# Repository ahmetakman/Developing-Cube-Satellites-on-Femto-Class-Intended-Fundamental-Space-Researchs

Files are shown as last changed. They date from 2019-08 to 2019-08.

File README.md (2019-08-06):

# Developing-Cube-Satellites-on-Femto-Class-Intended-Fundamental-Space-Researchs

The project won the second place in the coding category in the TUBITAK Inter-High School Research Projects Competition.
Project designed in Autodesk Eagle Pcb design program
#pasword for zip : licenced_design

Projenin Türkçe ismi "Temel Uzay Araştırmalarına Yönelik Femto Sınıfında Küp Uydu Geliştirilmesi"
Proje Tübitak Liseslerarası Araştırma Projeleri Yarışmasında kodlama dalında bölge ikinciliği aldı.
Proje Autodesk Eagle Pcb tasarım programında tasarlandı.
#zip dosyasının şifresi : licenced_design

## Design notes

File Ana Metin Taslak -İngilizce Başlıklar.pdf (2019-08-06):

THE REPORT OF THE PROJECT WHICH IS DEVELOPING CUBE SATELLITE ON FEMTO CLASS INTENDED FUNDAMENTAL SPACE RESEARCHS

TABLE OF CONTENTS

### 1.0 Introduction

Yapay uydular, Sputnik ile başlayan uzay çağının en önemli elemanları olmuşlardır.
Günümüzde | bu | uydular, | gerçekleştirdikleri | kritik | görevlerle | insanlığa | hizmet
etmektedirler. İletişim, uzaktan algılama, veri toplama, navigasyon, keşif ve bilimsel
deneyler | kullanıldıkları | alanlardan | sadece | bir | kısmını | oluşturmaktadır. | Uzay
teknolojisine yapılan yatırımlar hiç bir zaman boşa gitmemiş, mühendislikte ve bilimdeki ilerlemeleri tetikleyen bir unsur olmuştur. Ayrıca bu gelişmeler de uzay teknolojisinin ileriye gitmesinde ve gelişmesinde büyük rol oynamıştır. Günümüzün uzay araçları ile onların atalarını karşılaştırdığımızda, bugünün uydularının çok daha küçük, hafif ve kompakt yapılar olduklarını görürüz. Uzayla ilgili bir projenin risk ve maliyet gereksinimlerini dikkate alırsak, bu durum çok önem arz etmektedir. Yüzlerce, hatta binlerce kilogramlık uydular, aynı zamanda görev bütçeleri için de ağır bir yük teşkil etmektedirler. Bu nedenle, küçük uydular tasarımları, testleri, onaylaması ve fırlatma maliyetlerindeki avantajlardan dolayı dikkat çekmektedirler. (Sarı, 2010) (Aslan, 2015).

Son yıllarda küp uyduların artan yetenekleri ile uzay sektöründe büyük atılımlar meydana gelmiştir. Üretilen ve uzayda çalışan ilk küp uydularla uzay kalifiye ürünler de kullanmadan uzay sistemlerinin geliştirilebileceği ve farklı görevlerde kullanılabileceği gösterilmiştir. Bir öğrenci eğitim projesi olarak başlayan küp uydu tasarım projeleri şimdi farklı amaçlarla gelişerek yüksek öncelikli bir konu haline gelmiştir. Birçok kişi ve kurum, bu konu hakkında çalışmaları teşvik etmektedir. (Akay, 2012)

Küp uydular ile temel uzay çalışmaları yapılabildiği gibi, gözetleme uyduları gibi ileri seviye çalışmalar da çoklu küp uydular kullanılarak belli ölçülerde yapılabilmektedir. (Baş, 2017)

### 1.1 Goal of The Project

Ülkemizde yeni gelişmeye başlayan uzay sektöründe yapılan çalışmaların azlığı sebebiyle küçük çapta uyduların erişimi ve geliştirilmesi göreceli olarak daha kolaydır. Ülkemizde ve dünyada mevcut geliştirilmiş olan Femto (0-100 gr ağırlıklarında) pek az uydu bulunmaktadır. Bu uydular görev olarak temel telemetri verileri gönderebilen altsistemlerden oluşur. Proje kapsamında geliştirdiğimiz uydu platformu ile var olan bu açığı gidererek temel uydu fonksiyonlarını yerine getirebilen ek görev yükü olarak kamera modülünü de bulunduran gömülü sistem çözümü niteliğinde bir platform geliştirmek bu projenin amacını oluşturmaktadır.

### 1.2 Electronic Design and Development

### 1.2.1 Component Selection: Projemizde ana işlem birimi olarak uzay ürünleri konusunda

geçmiş tecrübesi bulunan Texas Instruments firması tarafından geliştirilen SimpleLink CC1310 RF MCU (cc1310, 2016) tercih edilmiştir. Ultra Low Power sınıfı bir mcu (mikrodenetleyici) olan CC1310 çok düşük güç tüketimi sağlamaktadır. Ayrıca üzerinde gömülü durumda RF (radyo iletişim) çekirdeği de bulunmaktadır. Böylelikle sistem üzerinde iki ayrı ana birimi birleştirerek yerden tasarruf etmeyi sağladık. Sensör kartı üzerinde bulunmakta olan Mpu 9250 (Invensense, 2016) sensör entegresi jiroskop manyetometre ve ivmeölçer sensörlerini barındırmaktadır sensör kartı üzerindeki BME280 (Bosch, 2015) entegresi ısı sıcaklık basınç nem ölçümleri yapabilmektedir.

Uydu platformu üzerinde kamera arayüz kartı ve kamera bulundurmaktadır. Kamera olarak dcmi arayüzüne sahip (OV5640,2011) opsiyonel görüntü sensörüne yer verdik. Kamera arayüz kartında ise ST Microelectronics firması tarafından üretilen stm32l4 (St MicroElectronics

,2017) serisi Ultra Low Power sınıfı dcmi arayüzüne sahip çok düşük güç tüketimli bir mcu kullandık.

Sistem üzerindeki hafıza kartı (sd card) modülü ile toplanan verilerin kaydedilmesini sağlayarak kapsama alanı dışında elde edilen verilerin kaybolmamasını sağladık.

Enerji ve enerji yönetiminde düşük enerji tüketimine sahip Texas Instruments tarafından üretilen BQ25504 (Texas Instruments, 2015) enerji yönetim entegresi kullanılmıştır.

Komponent seçimlerinde uzay kabul edilebilirlik standartları göz önünde bulundurulmuştur. Komponentlerin görev açıklaması ve teknik ayrıntılar raporun ilgili tasarım bölümünde mevcuttur.

1.2.2 Eagle: İlk olarak cadsoft firması tarafından geliştirilen daha sonra da Autodesk firması tarafından satın alınan elektronik tasarım aracı olan Eagle programının projede 8.5.1 sürümü kullanılmıştır. Gelişmiş şematik ve pcb tasarım arayüzü geniş kütüphane desteği sebebiyle Eagle programı tercih edilmiştir. (Autodesk, 2017)

### 1.3 Embedded System Programming

### 1.3.1 Sensor Controller Studio and Code Composer Studio: Texas Instruments Tarafından

geliştirilen ve kendi gömülü sistem ürünlerini programlamak için geliştirilmiş programlar ve dillerdir. Sensor Controller Studio (Texas Instruments,2017) uyduda kullandığımız cc1310 işlemcisinin içinde bulunan Sensor Controller Engine çekirdeğini c dilinde programlamaya pin konfigürasyonunu yapmaya imkân veren güçlü bir araçtır. Code Composer Studio (Texas Instruments,2017) ile de işlemcimizin ana çekirdeğini programlamak için kullandığımız C dilinde (Deitel, 2010) programlama seçeneği sunan güçlü bir araçtır.

### 1.3.2 Keil: Kamera arayüzü bloğunda kullandığımız stm32l4 işlemcisini programlamak için

kullanılan üreticinin de desteklediği C dilinde bir gömülü yazılım aracıdır. (Keil, 2017)

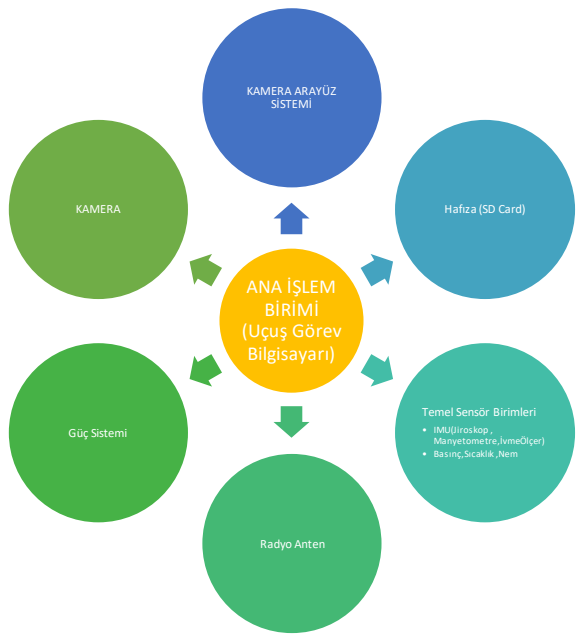
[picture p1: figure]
ANA İŞLEM BİRİMİ (Uçuş Görev Bilgisayarı); KAMERA ARAYÜZ SİSTEMİ; Hafıza (SD Card); Temel Sensör Birimleri; • IMU(Jiroskop , Manyetometre,İvmeÖlçer) • Basınç,Sıcaklık ,Nem; Radyo Anten; Güç Sistemi; KAMERA

Şekil 1.0 Femto Satellite General Relation Diagram

### 2.0 Method

Projede yer alan iki ana sistem olan, kamera sistemi ve ana sistem; iki ana parça olarak, elektronik tasarım ve programlama gerçekleştirilmiştir.

2.1 Proje Yapım Basamakları

2.1.1 Ana Görev Uçuş Bilgisayarı Kartı Tasarımı

2.1.2 Sensör ve RF Anten Kartı Tasarımı

2.1.3 Güç ve Güç Yönetim Sistemi Kartı Tasarımı

2.1.4 Kamera Arayüz Kartı Tasarımı

2.1.5 Kamera Kartı Tasarımı

2.1.6 Ana İşlemci Programlanması

2.1.6.1 Sensör Kontrolcü Çekirdeği Programlanması

2.1.6.2 Ana çekirdek Programlanması

2.1.7 Kamera Arayüzü Sistemi Programlanması

### 3.0 Finding and Applying

### 3.1 Main Mission Flight Computer Board Design

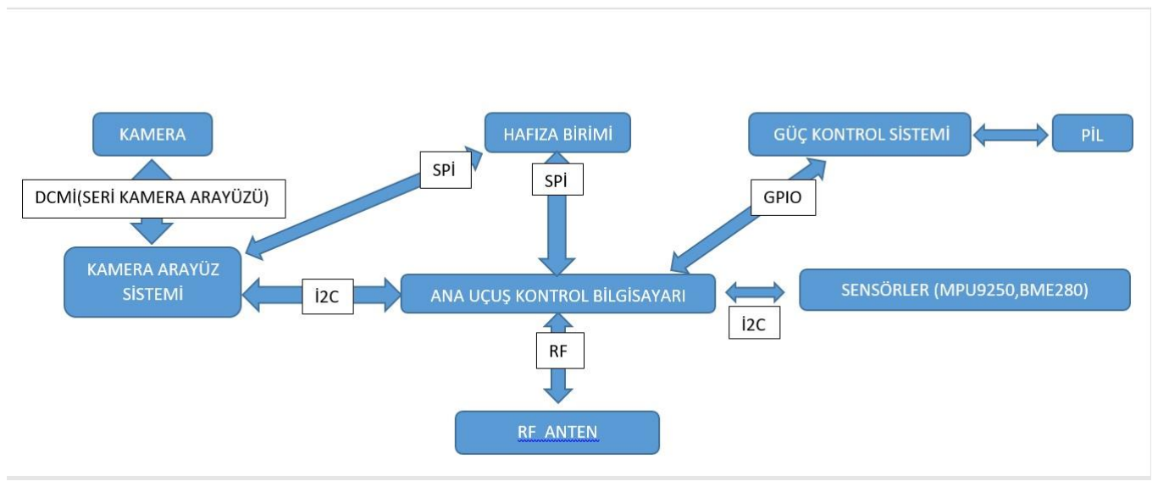
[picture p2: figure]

Şekil 1.1 Subsystems General Interface Diagram

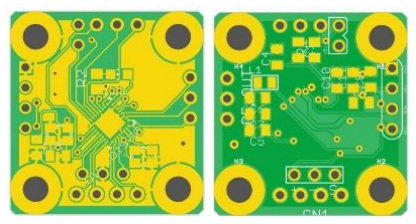
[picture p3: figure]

Şekil 1.2 Board Design Picture

Ana Görev Uçuş Bilgisayarı Kartı diğer altsistem birimlerinin tümünü yöneten kart konumundadır. Bu nedenle üzerinde bulunan ana işlem birimi cc1310 rfmcu entegresinin giriş ve çıkışları Şekil 1.1 de belirtilmiş olan arayüz diyagramımıza göre tasarlanmıştır. Diğer altsistemler ile gerçekleşecek olan iletişimi sağlamak üzere en uygun yerlere ilgili pinler yerleştirilmiştir. Kart üzerindeki oluşacak ısı, toprak (GND) hattının alt ve üst katmanda genişletilmesi ile dağıtılmıştır. Kart boyutları mekanik tasarım ile küp şeklinin tamamlanması için az bir farkla dikdörtgen konumlandırılmıştır.

### 3.2 Sensor and RF Antenna Board Design

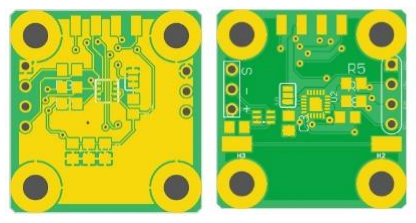
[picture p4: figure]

Şekil 1.3 Board Design Picture

Sensör ve RF Anten Kartı sistemde bulunan temel sensör birimlerini ve RF (radyo iletişimi) filtresi ile antenini üzerinde bulundur. Ana Görev bilgisayarı ile şekil 1.1 de belirtilmiş olan iletişimi sağlamak üzere ilgili pinler dahili jiroskop manyetometre ivmeölçer bulunduran MPU9250 IMU sensör entegresi ve dahili atmosferik sensör bulunan BME280 sensör entegresinden sağlanan arayüz çıkışları Ana Görev Uçuş Bilgisayarı Kartı ile üst üste tam oturacak şekilde bırakılmıştır. Bu kartın tasarımında da ısı dağılımı ve mekanik boyutlar gibi konularda Ana Görev Uçuş Bilgisayarı Kartı ile aynı anlayış benimsenmiştir.

### 3.3 Power and Power Management System Board Design

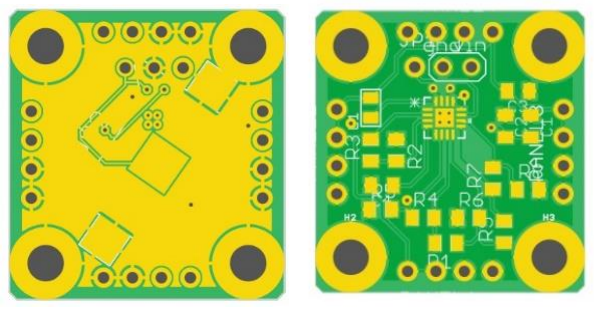
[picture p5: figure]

Şekil 1.4 Board Design Picture

Uydumuzun çevresini kaplayarak enerji ihtiyacını sağlayan güneş panel hücrelerinden gelen enerjiyi kontrol ederek pili şarj eden ve sisteme verilen enerjiyi kontrol eden Texas Instruments firması tarafından üretilen BQ25504 enerji yönetim entegresini üzerine konumlandırmış olduğumuz güç ve güç yönetim kartımız yine diğer alt sistemlerle aynı boyutlarda ve uyum içerisinde tasarlanmıştır. Kartımızın alt katmanında yalnızca pil yuvası bulunmaktadır diğer tüm komponentler üst katmandadır. Ayrıca enerji yönetim entegresi ana kontrol birimine pil hakkında bilgi de vermektedir.

### 3.4. Camera Interface Board Design

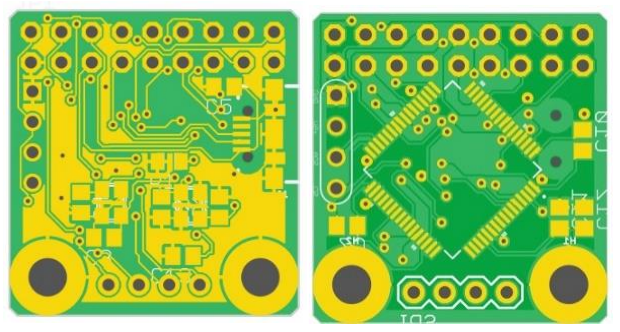
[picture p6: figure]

Şekil 1.5 Board Design Picture

Uydumuzu diğer benzerlerinden ayıran en önemli özellik olan kamera bulundurma yetisini kamera verilerini işleyerek fotoğraf haline getirebilen kamera arayüz kartımız kazandırmaktadır. Kartımız üzerinde ARM tabanlı bir mikro işlemci olan STM32L4 mevcut. Kartımız şekil 1.1 da yer aldığı gibi DCMI (seri kamera arayüzü) portu ile kendi geliştirmiş olduğumuz kamera modülü ve aynı pin çıkışlarına sahip diğer kamera modülleri ile de kullanılmasına imkân veren bir yapıda. Kartımız diğer altsistem kartları ile aynı felsefe ve tam uyum içerisinde tasarlanmıştır.

### 3.5. Camera Board Design

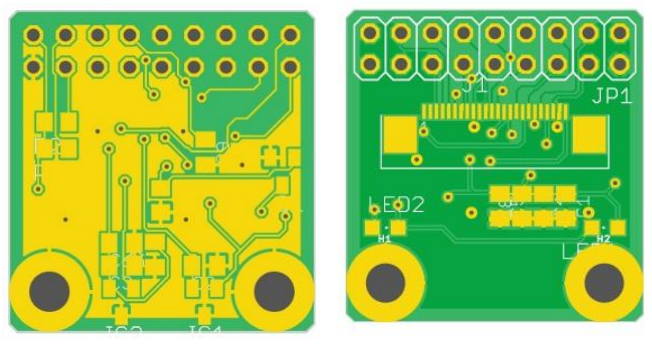
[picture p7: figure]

Şekil 1.6 Board Design Picture

Kamera kartımız omnivision firması tarafından geliştirilmiş olan OV5640 görüntü sensörüne tam uyum sağlayarak şekil 1.1 da gösterilen DCMI portu ile çıkış verilmiştir. Kartımız diğer altsistemlerle tam uyum sağlayan bir yapıdadır (şekil 1.6).

### 3.6. Main Microcontroller Programming

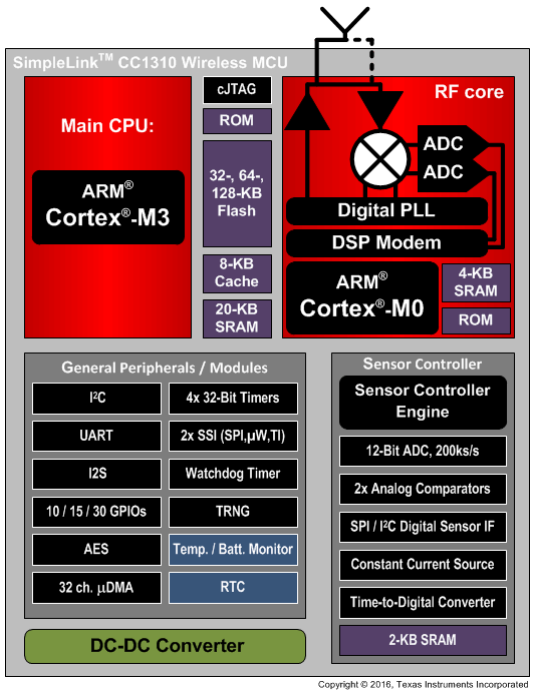
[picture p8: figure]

Şekil 1.7 Main Microcontroller Functional Diagram

Projemizde temel uydu fonksiyonlarını yerine getirirken aynı zamanda enerji tüketimini en alt düzeyde tutmak mecburiyetiyiz. Bundan ötürü sistemimizde kullanmış olduğumuz Ana işlem birimi olan CC1310 RF mcu’su da düşük güç tüketimi odaklı tasarıma sahip . Şekil 1.7 de görebileceğiniz üzere ikisi programlamaya ihtiyaç duyulan biri 3 ayrı çekirdekten oluşmaktadır. Ana çekirdek code composer studio ortamında sensör kontrolcüsü ise sensor controller studio ortamında C dili ile kodlanarak programlanmıştır.

### 3.6.1. Sensor Controller Core Programming

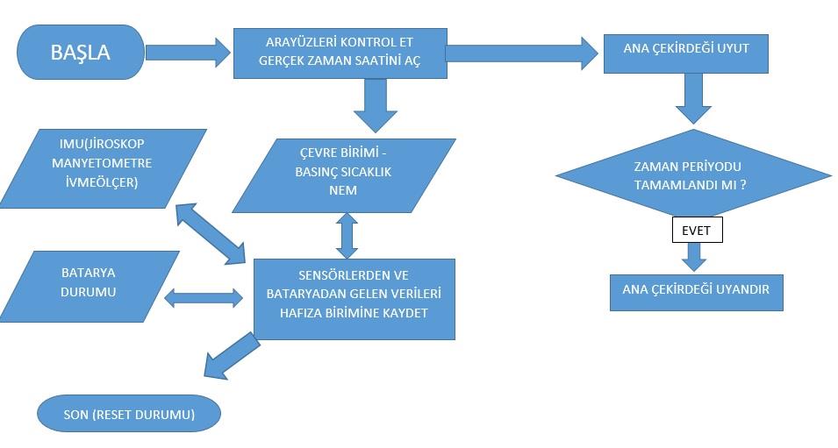
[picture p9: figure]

Şekil 1.8 Sensor Controller Core Algorithm

CC1310 RF mcu’nun içerisinde enerji tüketimini en aza indirmek üzere ana işlemciye bağımlı slave (emir alan) durumunda bir sensör kontrolcü çekirdeği mevcuttur. Bu çekirdeği programlamak üzere Texas Instruments firmasının geliştirmiş olduğu Sensor Controller Studio gömülü yazılım aracını kullandık. Şekil 1.8’de akış şeması gösterildiği gibi Sistem standart durumda ana çekirdek uykuda sensör kontrolcü çekirdeği aktif olarak sensör verilerini okuyarak hafıza birimine yazmak ile görevli. Gerçek zaman saati ile (RTC) periyodik aralıklar ile ana çekirdeği uyandırmaya programladık.

### 3.6.2. Main Core Programming

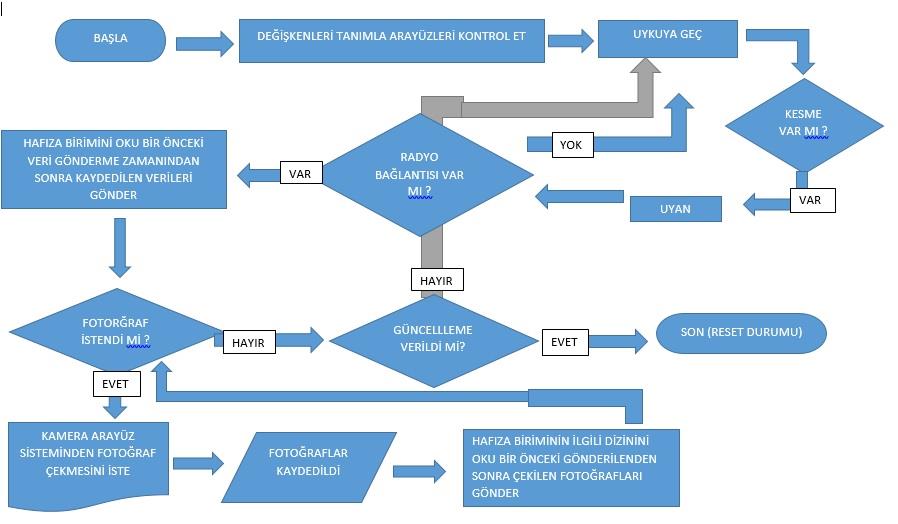
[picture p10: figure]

Şekil 1.9 Main Core Algorithm

CC1310 RF mcu’nun içerisinde gömülü bulunan ana çekirdek ARM Cortex M3 mimarisine sahiptir. Çekirek tüm sistemin emir vericisi (master) durumdadır. Açılmasının ardından Şekil 1.9’da görüleceği üzere uykuya geçer. Sensör kontrolcü çekirdeği uyandırdığı zaman yer istasyonu ile RF çekirdeğini kullanarak iletişim kurmaya çalışır eğer iletişim var ise elde edilen veriler paketler halinde gönderilerek tekrar uykuya geçer. Güç tüketimini en alt düzeye indirmek için sürekli uyku durumunda olan kamera altsistemini yalnızca yer istasyonu tarafından istendiği zaman uyandırarak veri göndermesi istenir.

### 3.7 Camera Inteface System Programming

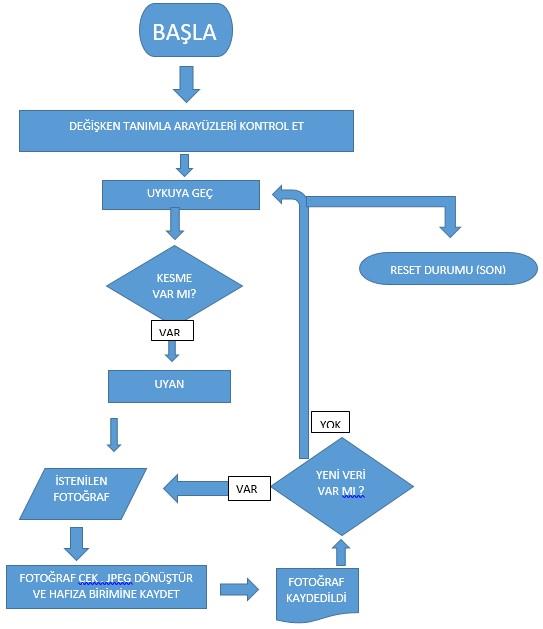
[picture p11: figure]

Şekil 2.0 Camera Interface Algorithm Platformumuzu diğer çalışmalardan ayrı bir yere koyan en önemli ayrıntı üzerinde kamera bulundurabilmesi oldu. Deneysel Yıldız Tarayıcı (Karabulut, 2017) olarak da kullanılabilecek olan kameramız yer istasyonunun isteğine göre çekim yeteneğine sahiptir. Kamera Arayüz sistemi kendi içerisinde STM32L4 serisi bir mcu bulundurmaktadır. Bu mcu ARM Cortex M4 mimarisine sahiptir. Ana kontrol işlemci bütününe göre emir alan (slave) hafıza birimi ve kameraya göre emir veren (master) durumundadır. Şekil 2.0’da verilen algoritmasında görüldüğü gibi sistem açılışın ardından arayüz kontrollerini yapar kamerayı kapatır ve uyku haline geçer. Uyandırıldığı zaman ana işlemcinin istediği özelliklerde (çözünürlük, poz süresi, poz sayısı vb.), kamerayı uyandırarak görüntü alır. Ardından görüntü verilerini JPEG formatına getirerek hafıza birimine yazar. Bu bilgiyi ana işlemciye göndererek beklemeye başlar eğer yeni bir emir gelmezse tekrar uykuya geçer.

### 3.8 Announcement of Codes

Gömülü sistemlerde en sık kullanılan dillerden biri olan C dili ile kodladığımız sistemimizin bazı kod parçalarını vererek açıklamaya çalıştık. Bu proje gibi gömülü sistem uygulamalarında elbette aynı algoritma kullanılarak, kodlar elektronikteki son ürüne göre şekillenerek son halini almaktadır. Tüm kodlar geliştirdiğimiz ve ilgili bölümde belirtmiş olduğumuz algoritmalara göre yazılmıştır.

### 3.8.1 sensor_controller_engine_satellite.c

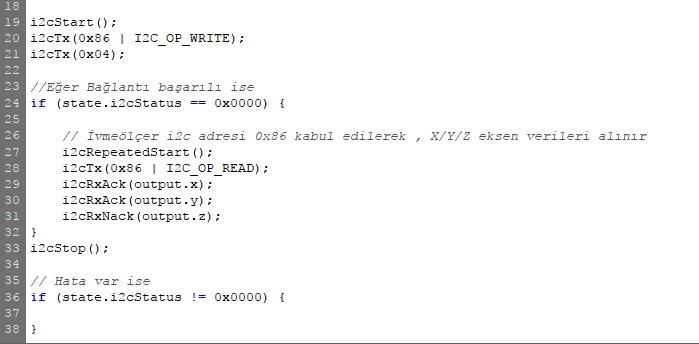
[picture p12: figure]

Uydu altsisteminin ana kontrol mikrodenetleyicisi içerisinde bulunan sensör kontrolcüsü çekirdeğinin Şekil 1.8 ‘de gösterilen algoritmasına göre kodladığımız Task’ın (Sensor Controller Studio içerisinde kod parçalarına verilen isimdir) bir parçası gösterilmiştir. Burada İvmeölçer sensörünün kontrolünün yapılarak veri alım işleminin yapılması açıklanmıştır. İlgili ayrıntılar yorum satırı olarak eklenmiştir.

### 3.8.2 main.c(ana çekirdek)

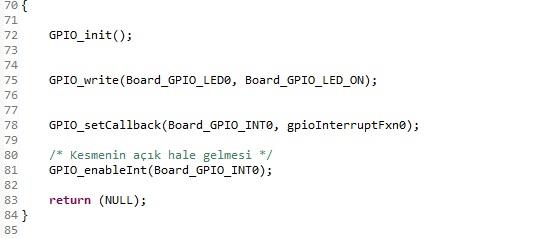
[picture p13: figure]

Sistemin yöneticisi durumdaki ana çekirdeğin güç tüketimini asgari düzeyde tutmak için kesmeler (interrupt) kullanılmaktadır. Sayfada genel giriş çıkış noktası üzerinden uyanarak kart üzerindeki LED’in yanmasını gösteren bir kod örneği verilmiştir.

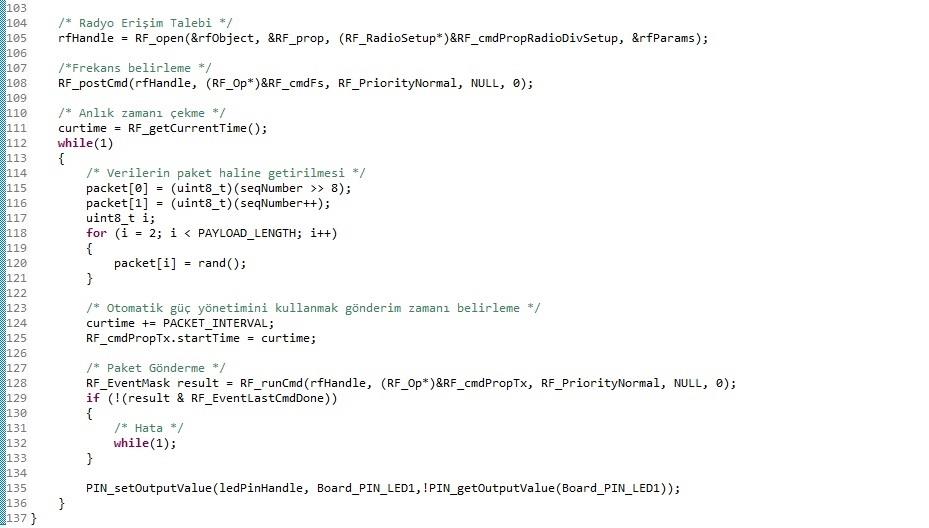
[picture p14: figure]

Uydu altsisteminin yer istasyonu ile iletişimini sağlayan gömülü RF çekirdeği ana çekirdek tarafından yönetilmektedir. Sayfada verilen parçada yer istasyonu ile iletimi sağlamak amacıyla veri kaybının önüne geçen paket gönderim yöntemi ile yazılmış bir kod mevcuttur. Ayrıntıları açıklama satırlarında mevcuttur.

### 3.8.2 kamera_arayuz.c (kamera arayüz sistemi)

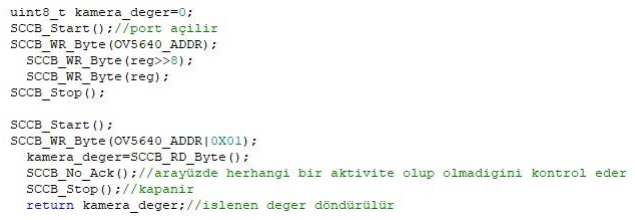
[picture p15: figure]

Uydumuzun görüntü alımını sağlayan kamerayı kullanmak üzere oluşturmuş olduğumuz kamera arayüz sistemi sccb ile dcmi arayüzlerini birleyerek görüntü sensörünün kullanımını sağlamakta. Bu sayfada yer alan kodda kamera arayüz çekirdeği arayüzünü kontrol altına alıyor. Ayrıntılar açıklama satırlarında mevcuttur.

Burada kodlarımızı açıkladığımız bölümün sonuna geldik. Algoritmaya bağlı kalarak güç tüketimi ve başarımı önceleyerek projemizi kodladık.

### 4.0 Results and Discussions

Ülkemizde ve dünyada pek az örneği bulunan femto uydulara yönelik bir araştırma ardından geliştirme çalışması yaptık. Benzer diğer çalışmalardan biri Hintli bir gencin geliştirmiş olduğu KALAM-SAT mevcut bu uyduda amaç yalnızca 4 saat yörüngede kalarak elde ettiği sensör verilerini dünyaya aktarmaktı. 22 Haziran 2017 tarihinde de fırlatması gerçekleşti. Platformumuzun bu çalışmadan üstün yanları, tekrar şarj edilebilmek üzere güneş panelleri bulundurması, kamera bulundurması, daha küçük boyutlarda olması (Kalamsat yaklaşık 37 mm kenar boyutlarında bir küp, geliştirmiş olduğumuz platform ise yaklaşık 27 mm kenarlı bir küp) , daha uzun süreli ve çeşitli (örn. Serbest uzay araştırması) görevlere elverişli olması. Bir diğer çalışma ise Cornell Üniversitesinden Z. Manchester isimli doktora öğrencisinin (kicksat, 2011) geliştirmiş olduğu ve kickstarter platformu üzerinden fonlayarak uzaya göndermiş olduğu KickSat projesi jiroskop ve manyetometre verilerini dünyaya aktararak serbest uzayda veya dünya yörüngesinde görev yapmak amaçlı geliştirildi. İlk versiyonu olan KickSat 1 teknik bir arıza sebebiyle görevini gerçekleştiremedi. İkinci versiyonu geliştirilme aşamasında.

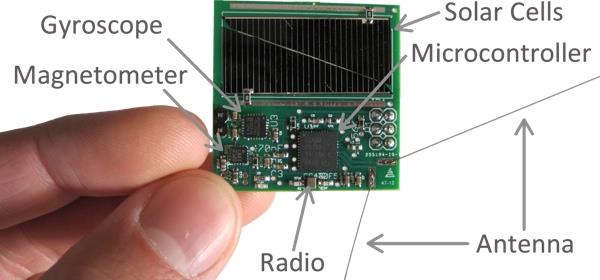
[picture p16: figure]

Şekil 2.1 KickSat Platformu Görseli

Platformumuzun bu çalışmadan üstün yanları üzerinde şarj edilebilir bir batarya bulundurarak ışık enerjisinin olmadığı ortamlarda da ölçüm yapabilmesi, üzerinde kamera bulundurması, daha küçük kenar yapısında olması (KickSat 35x35 mm boyutlarında bir tek kart, Geliştirmiş olduğumuz platform yaklaşık 27 mm kenarlı bir küp) ve daha güçlü işlem yapısı sıralanabilir. Zayıf yanı olarak da daha büyük bir hacme sahip olmasını söyleyebiliriz.

Projenin yazıldığı tarih olan 01.01.2018’te platformumuz üzerinde kamera bulundurabilen en küçük uydu sıfatını taşımaktadır.

### 5.0 Suggestions

Küçük uyduların popülerleşmesi elektronikteki gelişmelere paralel olarak ucuzlayan ürünlerin ulaşılabilirliğinin artması ile olmuştur. Projemizin geliştirme aşamasında pratikte el yapımı üretime elverişli olması maliyet olarak ucuz olması belirleyici unsurlardan biri oldu. Örnek verecek olursak el ile prototiplemeye uygun olması için 805 kılıflı direnç ve kapasitörler kullandık ve daha ucuz olması için 2 katlı bir pcb tasarladık. Bu yüzden eğer daha fazla bütçeye ve kalifiye kişiye sahip ekipler ar-ge çalışması yaparsa daha küçük boyutlar elde edilebilir.

Proje kapsamı, aynı kicksat projesinde olduğu gibi, 30x10 cm standartlarında bir 3U uydu yapısı içerisine çok sayıda femto uydunun konularak yaylı bir fırlatıcı ile uzayda ikinci bir dağılımını da içine alarak genişleyebilir.

Projede enerji ihtiyacı ve boyutları itibariyle iyon motorları tepki tekeri gibi hareket elemanlarına yer vermedik. Fakat farklı görevler dahilinde bu tür bir hareket elemanı da entegre edilebilir.

Projede kullandığımız kameramız yıldız tarama işlemi için deneysel nitelikte. Sadece yıldız tarama için geliştirilmiş kamera sistemlerinin yeniden tasarlanarak daha küçük boyutlara getirilebilmesi mümkün.

### 6.0 References

Sarı, Ö. (2010). İTÜpSAT1 Uydusunun Entegrasyonu ve Testleri. (Yayımlanmış Yüksek Lisans Tezi) .İstanbul Teknik Üniversitesi, Fen Bilimleri Enstitüsü, İstanbul.

Akay, M.C. (2012). İTÜpSAT11: Yönelim Kontrolüne Sahip Nano Uydular İçin Yüksek Yeterlilikli Platform Geliştirilmesi. (Yayımlanmış Yüksek Lisans Tezi) .İstanbul Teknik Üniversitesi, Fen Bilimleri Enstitüsü, İstanbul.

Baş, M.E (2017). Küp Uydular İçin Tümleşik Uçuş Bilgisayarı ve
Haberleşme Sistemi. (Yayımlanmış Yüksek Lisans Tezi) .İstanbul Teknik Üniversitesi, Fen Bilimleri Enstitüsü, İstanbul.

Karabulut, B. (2017) Nano/Micro Uydular İçin Yıldız Tarayıcı Tasarımı. (Yayımlanmış Yüksek Lisans Tezi) .İstanbul Teknik Üniversitesi, Fen Bilimleri Enstitüsü, İstanbul.

Deitel P./Deitel H. (2010) C How to Program, 6/e C Programlama Dili

Texas Instruments (2016) SimpleLink™ Sub-1 GHz Ultra-Low Power Wireless Microcontroller: http://www.ti.com/product/CC1310

Invensense (2016) MPU-9250 Product Specification : http://www.invensense.com/wp-content/uploads/2015/02/PS-MPU-9250A-01-v1.1.pdf

Bosch (2015) BME-280 Product Specification:https://ae-bst.resource.bosch.com/media/_tech/media/datasheets/BST-BME280_DS001-11.pdf (https://ae-bst.resource.bosch.com/media/_tech/media/datasheets/BST-BME280_DS001-11.pdf)

Omnivision (2011) OV54640 : https://cdn.sparkfun.com/datasheets/Sensors/LightImaging/OV5640_datasheet.pdf

St MicroElectronics (2017) STM32L4A6xG : http://www.st.com/en/microcontrollers/stm32l4a6rg.html

Texas Instruments (2015) BQ25504 : http://www.ti.com/product/BQ25504

Texas Instruments (2017) Sensor Controller Studio : http://www.ti.com/tool/sensor-controller-studio (http://www.ti.com/tool/sensor-controller-studio)

Texas Instruments (2017)Code Composer Studio: http://www.ti.com/tool/CCSTUDIO

Keil (2017) Arm Keil MDK : http://www.keil.com

Autodesk (2017) EAGLE : https://www.autodesk.com/products/eagle/overview

Aslan, A. R. (2015) http://www.hho.edu.tr/uzhaf/pdf/RustemASLAN.pdf

KalamSat (2017) Wikipedia : https://en.wikipedia.org/wiki/Kalam_SAT

Manchester Z. (2011) Kicksat http://kicksat.github.io

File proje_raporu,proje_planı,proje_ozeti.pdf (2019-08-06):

## Temel Uzay Araştırmalarına Yönelik Femto Sınıfında Küp Uydu Geliştirilmesi Projesi Özeti

Gönderilen ilk uydudan bu yana uzay çalışmalarının ana unsuru yapay uydular olmuştur. Son yıllarda çok büyük hızlarla gelişmekte olan uzay sektöründe küçük uydulara olan ilgi gün geçtikçe artmaktadır. Bir öğrenci projesi olarak başlayan küp uydular günümüzde önemli görevler yüklenerek fırlatımı gerçekleştirilmektedir. Dünyada ve ülkemizde pek az sayıda bulunan femto sınıfında uydular, bu uyduların en küçük halidir. Var olan bu açığı kapatmak için femto sınıfında bir uydu platformu ortaya koymak üzere araştırma ve geliştirme çalışması yaptık. Literatür taraması ve veri toplanması aşamasında konusunda bilgili kişilerin eserleri referans alınarak mümkün olan en iyi tasarımı yapmaya çalıştık. Kodlama kısmında ise başarımı önceleyerek verimli bir çalışma ortaya koymaya gayret gösterdik. Platformumuzun diğer femto uydulardan en büyük farkı üzerinde deneysel kamera bulundurabilmesidir. Kamera ile fotoğraf çekme fonksiyonunu yıldız tarayıcı olarak da kullanarak uydunun yönelimi hakkında diğer uygulamalara oranla daha kesin bilgiler elde edilebilmektedir. Projemizin yazıldığı tarihlerde platformumuz üzerinde kamera bulundurabilen en küçük uydu sıfatını taşımaktadır.

Anahtar kelimeler: Femto Uydu, Küçük Uydu Altsistemleri, Gömülü Sistemler, Yıldız Tarayıcı, Uydu yönelim tespiti, telemetri.

## Temel Uzay Araştırmalarına Yönelik Femto Sınıfında Küp Uydu Geliştirilmesi Projesi Planı

### 1. Amaç ve Kapsam: Ülkemizde yeni gelişmeye başlayan uzay sektöründe yapılan

çalışmaların azlığı sebebiyle küçük çapta uyduların erişimi ve geliştirilmesi göreceli olarak daha kolaydır. Ülkemizde ve dünyada mevcut geliştirilmiş olan Femto (0-100 gr ağırlıklarında) pek az uydu bulunmaktadır. Bu uydular görev olarak temel telemetri verileri gönderebilen altsistemlerden oluşur. Proje kapsamında geliştirdiğimiz uydu platformu ile var olan bu açığı gidererek temel uydu fonksiyonlarını yerine getirebilen ek görev yükü olarak kamera modülünü de bulunduran gömülü sistem çözümü niteliğinde bir platform geliştirmek bu projenin temel amacını oluşturmaktadır. Projemiz, farklı görevlere entegre olabilmesi amaçlanan platformumuzun uydu kısmının elektronik ve yazılımsal geliştirilmesini kapsamaktadır. Veri alınan yer istasyonu proje kapsamına dâhil değildir. Uçuşun gerçekleşme aşaması proje kapsamında değildir.

2. Yöntem ve Gereçler: Uydu, uzay yeterlilik koşulları araştırılacaktır. Küçük boyutta uydular ile ilgili geçmiş çalışmalar araştırılacaktır. Uydu altsistemleri ve küçük boyutta uydular ile ilgili yazılmış tezler incelenecektir. Gerçekleştirilecek inovasyon noktaları belirlenecektir. Elektronik tasarım ve kodlama için uygun malzeme seçimi yapılacaktır. Elektronik mühendisleri ile görüşülüp tavsiyeler dâhilinde en uygun elektronik tasarım yapılacaktır. Ardından platform başlangıç kodlaması yapılacaktır.

İş-Zaman Tablosu

İŞİN TANIMI | AYLAR
| AĞUSTOS | EYLÜL | EKİM | KASIM | ARALIK | OCAK
LİTERATÜR TARAMASI | X | X
VERİ TOPLANMASI | X | X | X | X | X
TASARIM GELİŞTİRME | | | X | X | X
PLATFORM KODLANMASI | | | | X | X
PROJE RAPORU YAZIMI | | | | | X | X

## Temel Uzay Araştırmalarına Yönelik Femto Sınıfında Küp Uydu Geliştirilmesi Projesi Raporu

İÇİNDEKİLER

### 1.0 Giriş

Yapay uydular, Sputnik ile başlayan uzay çağının en önemli elemanları olmuşlardır.
Günümüzde | bu | uydular, | gerçekleştirdikleri | kritik | görevlerle | insanlığa | hizmet
etmektedirler. İletişim, uzaktan algılama, veri toplama, navigasyon, keşif ve bilimsel
deneyler | kullanıldıkları | alanlardan | sadece | bir | kısmını | oluşturmaktadır. | Uzay
teknolojisine yapılan yatırımlar hiç bir zaman boşa gitmemiş, mühendislikte ve bilimdeki ilerlemeleri tetikleyen bir unsur olmuştur. Ayrıca bu gelişmeler de uzay teknolojisinin ileriye gitmesinde ve gelişmesinde büyük rol oynamıştır. Günümüzün uzay araçları ile onların atalarını karşılaştırdığımızda, bugünün uydularının çok daha küçük, hafif ve kompakt yapılar olduklarını görürüz. Uzayla ilgili bir projenin risk ve maliyet gereksinimlerini dikkate alırsak, bu durum çok önem arz etmektedir. Yüzlerce, hatta binlerce kilogramlık uydular, aynı zamanda görev bütçeleri için de ağır bir yük teşkil etmektedirler. Bu nedenle, küçük uydular tasarımları, testleri, onaylaması ve fırlatma maliyetlerindeki avantajlardan dolayı dikkat çekmektedirler. (Sarı, 2010) (Aslan, 2015).

Son yıllarda küp uyduların artan yetenekleri ile uzay sektöründe büyük atılımlar meydana gelmiştir. Üretilen ve uzayda çalışan ilk küp uydularla uzay kalifiye ürünler de kullanmadan uzay sistemlerinin geliştirilebileceği ve farklı görevlerde kullanılabileceği gösterilmiştir. Bir öğrenci eğitim projesi olarak başlayan küp uydu tasarım projeleri şimdi farklı amaçlarla gelişerek yüksek öncelikli bir konu haline gelmiştir. Birçok kişi ve kurum, bu konu hakkında çalışmaları teşvik etmektedir. (Akay, 2012)

Küp uydular ile temel uzay çalışmaları yapılabildiği gibi, gözetleme uyduları gibi ileri seviye çalışmalar da çoklu küp uydular kullanılarak belli ölçülerde yapılabilmektedir. (Baş, 2017)

### 1.1 Projenin Amacı

Ülkemizde yeni gelişmeye başlayan uzay sektöründe yapılan çalışmaların azlığı sebebiyle küçük çapta uyduların erişimi ve geliştirilmesi göreceli olarak daha kolaydır. Ülkemizde ve dünyada mevcut geliştirilmiş olan Femto (0-100 gr ağırlıklarında) pek az uydu bulunmaktadır. Bu uydular görev olarak temel telemetri verileri gönderebilen altsistemlerden oluşur. Proje kapsamında geliştirdiğimiz uydu platformu ile var olan bu açığı gidererek temel uydu fonksiyonlarını yerine getirebilen ek görev yükü olarak kamera modülünü de bulunduran gömülü sistem çözümü niteliğinde bir platform geliştirmek bu projenin amacını oluşturmaktadır.

### 1.2 Elektronik Tasarım ve Geliştirme

### 1.2.1 Komponent Seçimi: Projemizde ana işlem birimi olarak uzay ürünleri konusunda geçmiş

tecrübesi bulunan Texas Instruments firması tarafından geliştirilen SimpleLink CC1310 RF MCU (cc1310, 2016) tercih edilmiştir. Ultra Low Power sınıfı bir mcu (mikrodenetleyici) olan CC1310 çok düşük güç tüketimi sağlamaktadır. Ayrıca üzerinde gömülü durumda RF (radyo iletişim) çekirdeği de bulunmaktadır. Böylelikle sistem üzerinde iki ayrı ana birimi birleştirerek yerden tasarruf etmeyi sağladık. Sensör kartı üzerinde bulunmakta olan Mpu 9250 (Invensense, 2016) sensör entegresi jiroskop manyetometre ve ivmeölçer sensörlerini barındırmaktadır sensör kartı üzerindeki BME280 (Bosch, 2015) entegresi ısı sıcaklık basınç nem ölçümleri yapabilmektedir.

Uydu platformu üzerinde kamera arayüz kartı ve kamera bulundurmaktadır. Kamera olarak dcmi arayüzüne sahip (OV5640,2011) opsiyonel görüntü sensörüne yer verdik. Kamera arayüz kartında ise ST Microelectronics firması tarafından üretilen stm32l4 (St MicroElectronics ,2017) serisi Ultra Low Power sınıfı dcmi arayüzüne sahip çok düşük güç tüketimli bir mcu kullandık.

Sistem üzerindeki hafıza kartı (sd card) modülü ile toplanan verilerin kaydedilmesini sağlayarak kapsama alanı dışında elde edilen verilerin kaybolmamasını sağladık.

Enerji ve enerji yönetiminde düşük enerji tüketimine sahip Texas Instruments tarafından üretilen BQ25504 (Texas Instruments, 2015) enerji yönetim entegresi kullanılmıştır.

Komponent seçimlerinde uzay kabul edilebilirlik standartları göz önünde bulundurulmuştur. Komponentlerin görev açıklaması ve teknik ayrıntılar raporun ilgili tasarım bölümünde mevcuttur.

1.2.2 Eagle: İlk olarak cadsoft firması tarafından geliştirilen daha sonra da Autodesk firması tarafından satın alınan elektronik tasarım aracı olan Eagle programının projede 8.5.1 sürümü kullanılmıştır. Gelişmiş şematik ve pcb tasarım arayüzü geniş kütüphane desteği sebebiyle Eagle programı tercih edilmiştir. (Autodesk, 2017)

### 1.3 Gömülü Sistem Programlama

### 1.3.1 Sensor Controller Studio ve Code Composer Studio: Texas Instruments Tarafından

geliştirilen ve kendi gömülü sistem ürünlerini programlamak için geliştirilmiş programlar ve dillerdir. Sensor Controller Studio (Texas Instruments,2017) uyduda kullandığımız cc1310 işlemcisinin içinde bulunan Sensor Controller Engine çekirdeğini c dilinde programlamaya pin konfigürasyonunu yapmaya imkân veren güçlü bir araçtır. Code Composer Studio (Texas Instruments,2017) ile de işlemcimizin ana çekirdeğini programlamak için kullandığımız C dilinde (Deitel, 2010) programlama seçeneği sunan güçlü bir araçtır.

### 1.3.2 Keil: Kamera arayüzü bloğunda kullandığımız stm32l4 işlemcisini programlamak için

kullanılan üreticinin de desteklediği C dilinde bir gömülü yazılım aracıdır. (Keil, 2017)

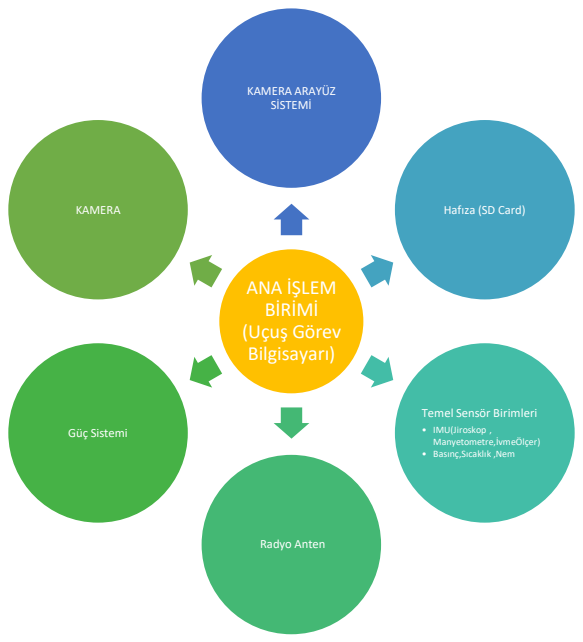
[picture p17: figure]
ANA İŞLEM BİRİMİ (Uçuş Görev Bilgisayarı); KAMERA ARAYÜZ SİSTEMİ; Hafıza (SD Card); Temel Sensör Birimleri; • IMU(Jiroskop , Manyetometre,İvmeÖlçer) • Basınç,Sıcaklık ,Nem; Radyo Anten; Güç Sistemi; KAMERA

Şekil 1.0 Femto Uydu Genel İlişki Diyagramı

### 2.0 Yöntem

Projede yer alan iki ana sistem olan, kamera sistemi ve ana sistem; iki ana parça olarak, elektronik tasarım ve programlama gerçekleştirilmiştir.

2.1 Proje Yapım Basamakları

2.1.1 Ana Görev Uçuş Bilgisayarı Kartı Tasarımı

2.1.2 Sensör ve RF Anten Kartı Tasarımı

2.1.3 Güç ve Güç Yönetim Sistemi Kartı Tasarımı

2.1.4 Kamera Arayüz Kartı Tasarımı

2.1.5 Kamera Kartı Tasarımı

2.1.6 Ana İşlemci Programlanması

2.1.6.1 Sensör Kontrolcü Çekirdeği Programlanması

2.1.6.2 Ana çekirdek Programlanması

2.1.7 Kamera Arayüzü Sistemi Programlanması

### 3.0 Bulgular ve Gerçekleştirme

### 3.1 Ana Görev Uçuş Bilgisayarı Kartı Tasarımı

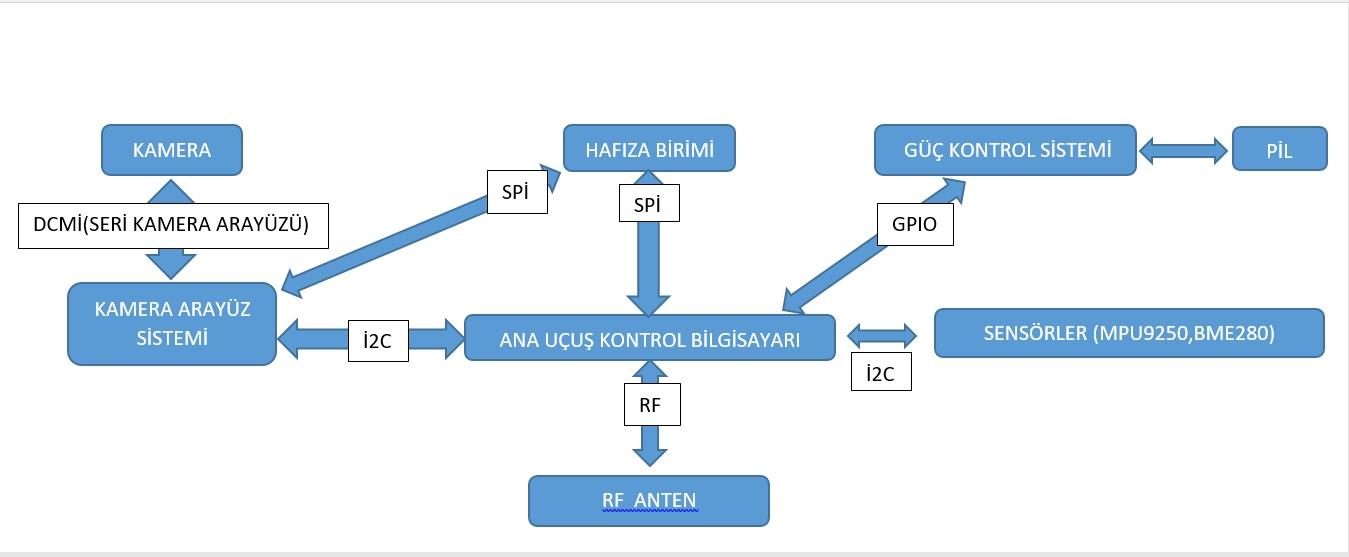
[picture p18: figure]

Şekil 1.1 Altsistem Genel Arayüz diyagramı


Şekil 1.2 Kart Tasarım Görseli

Ana Görev Uçuş Bilgisayarı Kartı diğer altsistem birimlerinin tümünü yöneten kart konumundadır. Bu nedenle üzerinde bulunan ana işlem birimi cc1310 rfmcu entegresinin giriş ve çıkışları Şekil 1.1 de belirtilmiş olan arayüz diyagramımıza göre tasarlanmıştır. Diğer altsistemler ile gerçekleşecek olan iletişimi sağlamak üzere en uygun yerlere ilgili pinler yerleştirilmiştir. Kart üzerindeki oluşacak ısı, toprak (GND) hattının alt ve üst katmanda genişletilmesi ile dağıtılmıştır. Kart boyutları mekanik tasarım ile küp şeklinin tamamlanması için az bir farkla dikdörtgen konumlandırılmıştır.

### 3.2 Sensör ve RF Anten Kartı Tasarımı

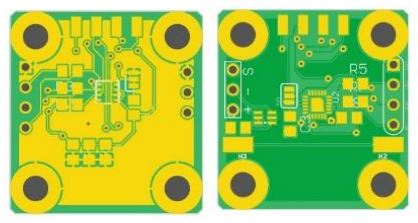
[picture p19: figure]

Şekil 1.3 Kart Tasarım Görseli

Sensör ve RF Anten Kartı sistemde bulunan temel sensör birimlerini ve RF (radyo iletişimi) filtresi ile antenini üzerinde bulundur. Ana Görev bilgisayarı ile şekil 1.1 de belirtilmiş olan iletişimi sağlamak üzere ilgili pinler dahili jiroskop manyetometre ivmeölçer bulunduran MPU9250 IMU sensör entegresi ve dahili atmosferik sensör bulunan BME280 sensör entegresinden sağlanan arayüz çıkışları Ana Görev Uçuş Bilgisayarı Kartı ile üst üste tam oturacak şekilde bırakılmıştır. Bu kartın tasarımında da ısı dağılımı ve mekanik boyutlar gibi konularda Ana Görev Uçuş Bilgisayarı Kartı ile aynı anlayış benimsenmiştir.

### 3.3 Güç ve Güç Yönetim Sistemi Kartı Tasarımı

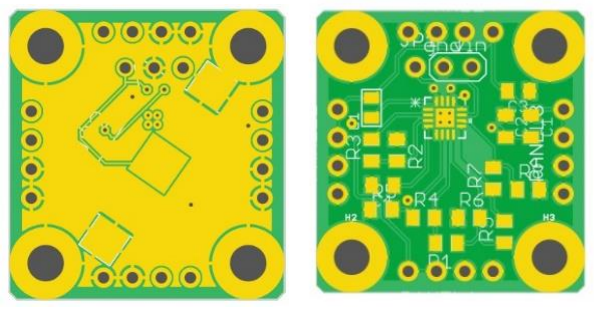
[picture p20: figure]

Şekil 1.4 Kart Tasarım Görseli

Uydumuzun çevresini kaplayarak enerji ihtiyacını sağlayan güneş panel hücrelerinden gelen enerjiyi kontrol ederek pili şarj eden ve sisteme verilen enerjiyi kontrol eden Texas Instruments firması tarafından üretilen BQ25504 enerji yönetim entegresini üzerine konumlandırmış olduğumuz güç ve güç yönetim kartımız yine diğer alt sistemlerle aynı boyutlarda ve uyum içerisinde tasarlanmıştır. Kartımızın alt katmanında yalnızca pil yuvası bulunmaktadır diğer tüm komponentler üst katmandadır. Ayrıca enerji yönetim entegresi ana kontrol birimine pil hakkında bilgi de vermektedir.

### 3.4. Kamera Arayüz Kartı Tasarımı

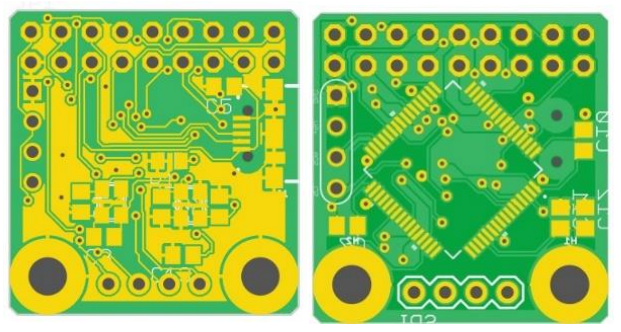
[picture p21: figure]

Şekil 1.5 Kart Tasarım Görseli

Uydumuzu diğer benzerlerinden ayıran en önemli özellik olan kamera bulundurma yetisini kamera verilerini işleyerek fotoğraf haline getirebilen kamera arayüz kartımız kazandırmaktadır. Kartımız üzerinde ARM tabanlı bir mikro işlemci olan STM32L4 mevcut. Kartımız şekil 1.1 da yer aldığı gibi DCMI (seri kamera arayüzü) portu ile kendi geliştirmiş olduğumuz kamera modülü ve aynı pin çıkışlarına sahip diğer kamera modülleri ile de kullanılmasına imkân veren bir yapıda. Kartımız diğer altsistem kartları ile aynı felsefe ve tam uyum içerisinde tasarlanmıştır.

### 3.5. Kamera Kartı Tasarımı

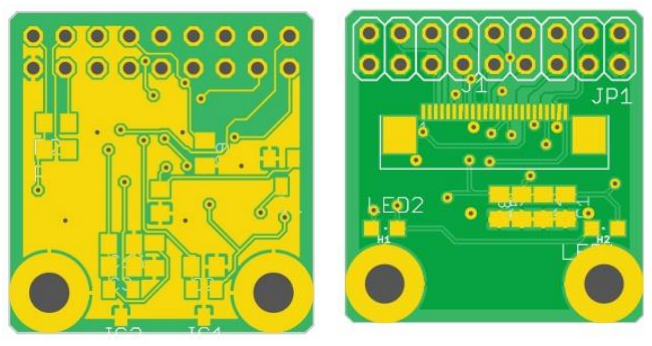
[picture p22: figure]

Şekil 1.6 Kart Tasarım Görseli

Kamera kartımız omnivision firması tarafından geliştirilmiş olan OV5640 görüntü sensörüne tam uyum sağlayarak şekil 1.1 da gösterilen DCMI portu ile çıkış verilmiştir. Kartımız diğer altsistemlerle tam uyum sağlayan bir yapıdadır (şekil 1.6).

### 3.6. Ana İşlemci Programlanması

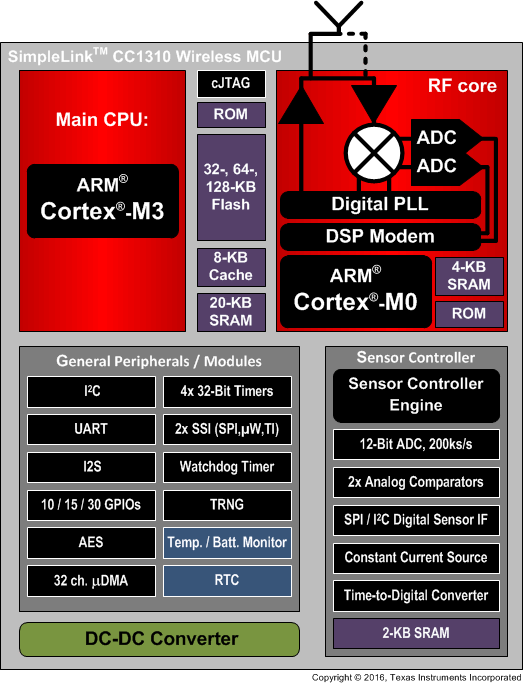
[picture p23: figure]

Şekil 1.7 ana işlemci fonksiyonel diyagramı

Projemizde temel uydu fonksiyonlarını yerine getirirken aynı zamanda enerji tüketimini en alt düzeyde tutmak mecburiyetiyiz. Bundan ötürü sistemimizde kullanmış olduğumuz Ana işlem birimi olan CC1310 RF mcu’su da düşük güç tüketimi odaklı tasarıma sahip . Şekil 1.7 de görebileceğiniz üzere ikisi programlamaya ihtiyaç duyulan biri 3 ayrı çekirdekten oluşmaktadır. Ana çekirdek code composer studio ortamında sensör kontrolcüsü ise sensor controller studio ortamında C dili ile kodlanarak programlanmıştır.

### 3.6.1. Sensör Kontrolcü Çekirdeği Programlanması


Şekil 1.8 Sensör Kontrolcüsü Çekirdeği Algoritması

CC1310 RF mcu’nun içerisinde enerji tüketimini en aza indirmek üzere ana işlemciye bağımlı slave (emir alan) durumunda bir sensör kontrolcü çekirdeği mevcuttur. Bu çekirdeği programlamak üzere Texas Instruments firmasının geliştirmiş olduğu Sensor Controller Studio gömülü yazılım aracını kullandık. Şekil 1.8’de akış şeması gösterildiği gibi Sistem standart durumda ana çekirdek uykuda sensör kontrolcü çekirdeği aktif olarak sensör verilerini okuyarak hafıza birimine yazmak ile görevli. Gerçek zaman saati ile (RTC) periyodik aralıklar ile ana çekirdeği uyandırmaya programladık.

### 3.6.2. Ana çekirdek Programlanması


Şekil 1.9 ana çekirdek Algoritması

CC1310 RF mcu’nun içerisinde gömülü bulunan ana çekirdek ARM Cortex M3 mimarisine sahiptir. Çekirek tüm sistemin emir vericisi (master) durumdadır. Açılmasının ardından Şekil 1.9’da görüleceği üzere uykuya geçer. Sensör kontrolcü çekirdeği uyandırdığı zaman yer istasyonu ile RF çekirdeğini kullanarak iletişim kurmaya çalışır eğer iletişim var ise elde edilen veriler paketler halinde gönderilerek tekrar uykuya geçer. Güç tüketimini en alt düzeye indirmek için sürekli uyku durumunda olan kamera altsistemini yalnızca yer istasyonu tarafından istendiği zaman uyandırarak veri göndermesi istenir.

### 3.7 Kamera Arayüzü Sistemi Programlanması


Şekil 2.0 Kamera Arayüzü Algroritması Platformumuzu diğer çalışmalardan ayrı bir yere koyan en önemli ayrıntı üzerinde kamera bulundurabilmesi oldu. Deneysel Yıldız Tarayıcı (Karabulut, 2017) olarak da kullanılabilecek olan kameramız yer istasyonunun isteğine göre çekim yeteneğine sahiptir. Kamera Arayüz sistemi kendi içerisinde STM32L4 serisi bir mcu bulundurmaktadır. Bu mcu ARM Cortex M4 mimarisine sahiptir. Ana kontrol işlemci bütününe göre emir alan (slave) hafıza birimi ve kameraya göre emir veren (master) durumundadır. Şekil 2.0’da verilen algoritmasında görüldüğü gibi sistem açılışın ardından arayüz kontrollerini yapar kamerayı kapatır ve uyku haline geçer. Uyandırıldığı zaman ana işlemcinin istediği özelliklerde (çözünürlük, poz süresi, poz sayısı vb.), kamerayı uyandırarak görüntü alır. Ardından görüntü verilerini JPEG formatına getirerek hafıza birimine yazar. Bu bilgiyi ana işlemciye göndererek beklemeye başlar eğer yeni bir emir gelmezse tekrar uykuya geçer.

### 3.8 Kodların açıklanması

Gömülü sistemlerde en sık kullanılan dillerden biri olan C dili ile kodladığımız sistemimizin bazı kod parçalarını vererek açıklamaya çalıştık. Bu proje gibi gömülü sistem uygulamalarında elbette aynı algoritma kullanılarak, kodlar elektronikteki son ürüne göre şekillenerek son halini almaktadır. Tüm kodlar geliştirdiğimiz ve ilgili bölümde belirtmiş olduğumuz algoritmalara göre yazılmıştır.

### 3.8.1 sensor_controller_engine_satellite.c


Uydu altsisteminin ana kontrol mikrodenetleyicisi içerisinde bulunan sensör kontrolcüsü çekirdeğinin Şekil 1.8 ‘de gösterilen algoritmasına göre kodladığımız Task’ın (Sensor Controller Studio içerisinde kod parçalarına verilen isimdir) bir parçası gösterilmiştir. Burada İvmeölçer sensörünün kontrolünün yapılarak veri alım işleminin yapılması açıklanmıştır. İlgili ayrıntılar yorum satırı olarak eklenmiştir.

### 3.8.2 main.c(ana çekirdek)


Sistemin yöneticisi durumdaki ana çekirdeğin güç tüketimini asgari düzeyde tutmak için kesmeler (interrupt) kullanılmaktadır. Sayfada genel giriş çıkış noktası üzerinden uyanarak kart üzerindeki LED’in yanmasını gösteren bir kod örneği verilmiştir.


Uydu altsisteminin yer istasyonu ile iletişimini sağlayan gömülü RF çekirdeği ana çekirdek tarafından yönetilmektedir. Sayfada verilen parçada yer istasyonu ile iletimi sağlamak amacıyla veri kaybının önüne geçen paket gönderim yöntemi ile yazılmış bir kod mevcuttur. Ayrıntıları açıklama satırlarında mevcuttur.

### 3.8.2 kamera_arayuz.c (kamera arayüz sistemi)

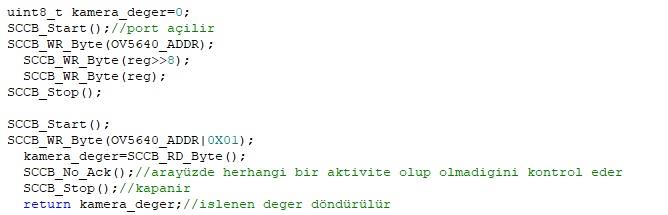
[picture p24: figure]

Uydumuzun görüntü alımını sağlayan kamerayı kullanmak üzere oluşturmuş olduğumuz kamera arayüz sistemi sccb ile dcmi arayüzlerini birleyerek görüntü sensörünün kullanımını sağlamakta. Bu sayfada yer alan kodda kamera arayüz çekirdeği arayüzünü kontrol altına alıyor. Ayrıntılar açıklama satırlarında mevcuttur.

Burada kodlarımızı açıkladığımız bölümün sonuna geldik. Algoritmaya bağlı kalarak güç tüketimi ve başarımı önceleyerek projemizi kodladık.

### 4.0 Sonuçlar ve Tartışma

Ülkemizde ve dünyada pek az örneği bulunan femto uydulara yönelik bir araştırma ardından geliştirme çalışması yaptık. Benzer diğer çalışmalardan biri Hintli bir gencin geliştirmiş olduğu KALAM-SAT mevcut bu uyduda amaç yalnızca 4 saat yörüngede kalarak elde ettiği sensör verilerini dünyaya aktarmaktı. 22 Haziran 2017 tarihinde de fırlatması gerçekleşti. Platformumuzun bu çalışmadan üstün yanları, tekrar şarj edilebilmek üzere güneş panelleri bulundurması, kamera bulundurması, daha küçük boyutlarda olması (Kalamsat yaklaşık 37 mm kenar boyutlarında bir küp, geliştirmiş olduğumuz platform ise yaklaşık 27 mm kenarlı bir küp) , daha uzun süreli ve çeşitli (örn. Serbest uzay araştırması) görevlere elverişli olması. Bir diğer çalışma ise Cornell Üniversitesinden Z. Manchester isimli doktora öğrencisinin (kicksat, 2011) geliştirmiş olduğu ve kickstarter platformu üzerinden fonlayarak uzaya göndermiş olduğu KickSat projesi jiroskop ve manyetometre verilerini dünyaya aktararak serbest uzayda veya dünya yörüngesinde görev yapmak amaçlı geliştirildi. İlk versiyonu olan KickSat 1 teknik bir arıza sebebiyle görevini gerçekleştiremedi. İkinci versiyonu geliştirilme aşamasında.


Şekil 2.1 KickSat Platformu Görseli

Platformumuzun bu çalışmadan üstün yanları üzerinde şarj edilebilir bir batarya bulundurarak ışık enerjisinin olmadığı ortamlarda da ölçüm yapabilmesi, üzerinde kamera bulundurması, daha küçük kenar yapısında olması (KickSat 35x35 mm boyutlarında bir tek kart, Geliştirmiş olduğumuz platform yaklaşık 27 mm kenarlı bir küp) ve daha güçlü işlem yapısı sıralanabilir. Zayıf yanı olarak da daha büyük bir hacme sahip olmasını söyleyebiliriz.

Projenin yazıldığı tarih olan 01.01.2018’te platformumuz üzerinde kamera bulundurabilen en küçük uydu sıfatını taşımaktadır.

### 5.0 Öneriler

Küçük uyduların popülerleşmesi elektronikteki gelişmelere paralel olarak ucuzlayan ürünlerin ulaşılabilirliğinin artması ile olmuştur. Projemizin geliştirme aşamasında pratikte el yapımı üretime elverişli olması maliyet olarak ucuz olması belirleyici unsurlardan biri oldu. Örnek verecek olursak el ile prototiplemeye uygun olması için 805 kılıflı direnç ve kapasitörler kullandık ve daha ucuz olması için 2 katlı bir pcb tasarladık. Bu yüzden eğer daha fazla bütçeye ve kalifiye kişiye sahip ekipler ar-ge çalışması yaparsa daha küçük boyutlar elde edilebilir.

Proje kapsamı, aynı kicksat projesinde olduğu gibi, 30x10 cm standartlarında bir 3U uydu yapısı içerisine çok sayıda femto uydunun konularak yaylı bir fırlatıcı ile uzayda ikinci bir dağılımını da içine alarak genişleyebilir.

Projede enerji ihtiyacı ve boyutları itibariyle iyon motorları tepki tekeri gibi hareket elemanlarına yer vermedik. Fakat farklı görevler dahilinde bu tür bir hareket elemanı da entegre edilebilir.

Projede kullandığımız kameramız yıldız tarama işlemi için deneysel nitelikte. Sadece yıldız tarama için geliştirilmiş kamera sistemlerinin yeniden tasarlanarak daha küçük boyutlara getirilebilmesi mümkün.

### 6.0 Kaynakça

Sarı, Ö. (2010). İTÜpSAT1 Uydusunun Entegrasyonu ve Testleri. (Yayımlanmış Yüksek Lisans Tezi) .İstanbul Teknik Üniversitesi, Fen Bilimleri Enstitüsü, İstanbul.

Akay, M.C. (2012). İTÜpSAT11: Yönelim Kontrolüne Sahip Nano Uydular İçin Yüksek Yeterlilikli Platform Geliştirilmesi. (Yayımlanmış Yüksek Lisans Tezi) .İstanbul Teknik Üniversitesi, Fen Bilimleri Enstitüsü, İstanbul.

Baş, M.E (2017). Küp Uydular İçin Tümleşik Uçuş Bilgisayarı ve
Haberleşme Sistemi. (Yayımlanmış Yüksek Lisans Tezi) .İstanbul Teknik Üniversitesi, Fen Bilimleri Enstitüsü, İstanbul.

Karabulut, B. (2017) Nano/Micro Uydular İçin Yıldız Tarayıcı Tasarımı. (Yayımlanmış Yüksek Lisans Tezi) .İstanbul Teknik Üniversitesi, Fen Bilimleri Enstitüsü, İstanbul.

Deitel P./Deitel H. (2010) C How to Program, 6/e C Programlama Dili

Texas Instruments (2016) SimpleLink™ Sub-1 GHz Ultra-Low Power Wireless Microcontroller: http://www.ti.com/product/CC1310

Invensense (2016) MPU-9250 Product Specification : http://www.invensense.com/wp-content/uploads/2015/02/PS-MPU-9250A-01-v1.1.pdf

Bosch (2015) BME-280 Product Specification:https://ae-bst.resource.bosch.com/media/_tech/media/datasheets/BST-BME280_DS001-11.pdf (https://ae-bst.resource.bosch.com/media/_tech/media/datasheets/BST-BME280_DS001-11.pdf)

Omnivision (2011) OV54640 : https://cdn.sparkfun.com/datasheets/Sensors/LightImaging/OV5640_datasheet.pdf

St MicroElectronics (2017) STM32L4A6xG : http://www.st.com/en/microcontrollers/stm32l4a6rg.html

Texas Instruments (2015) BQ25504 : http://www.ti.com/product/BQ25504

Texas Instruments (2017) Sensor Controller Studio : http://www.ti.com/tool/sensor-controller-studio (http://www.ti.com/tool/sensor-controller-studio)

Texas Instruments (2017)Code Composer Studio: http://www.ti.com/tool/CCSTUDIO

Keil (2017) Arm Keil MDK : http://www.keil.com

Autodesk (2017) EAGLE : https://www.autodesk.com/products/eagle/overview

Aslan, A. R. (2015) http://www.hho.edu.tr/uzhaf/pdf/RustemASLAN.pdf

KalamSat (2017) Wikipedia : https://en.wikipedia.org/wiki/Kalam_SAT

Manchester Z. (2011) Kicksat http://kicksat.github.io

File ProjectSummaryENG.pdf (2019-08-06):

THE SUMMARY OF THE PROJECT WHICH IS DEVELOPING CUBE SATELLITE ON FEMTO CLASS INTENDED FUNDAMENTAL SPACE RESEARCHS

Since the first satellite was launched, artifical satellites become main fact of space investigates. Recent years ins space sector which is being very fastly, small satellites becoming more and more popular and payed attention. Nowadays cube satellites which is began as a student projecti are launched with important missions. The smallest form of those satellites are femto class which are rare in either our country or World. We worked on search and development complete thşs lack and generate satellite platform in femto class. We tried to create the best desing possible by followşng up productions of people who are well informed about searching source and collecting data. In coding processwe gave effort to make work and success was our priority. Having an experimental camera is the most significant difference between our platform and others. It can collect more definite informations comparing with others about the aim of satellite, by using the camera as a star tracker. Our platform is called the smallest satellite incloude camera on date that our project was written.

Key Words: Femto Satellite, Small Satellite Subsytems, Embedded Systems, Star Tracker, Telemetry

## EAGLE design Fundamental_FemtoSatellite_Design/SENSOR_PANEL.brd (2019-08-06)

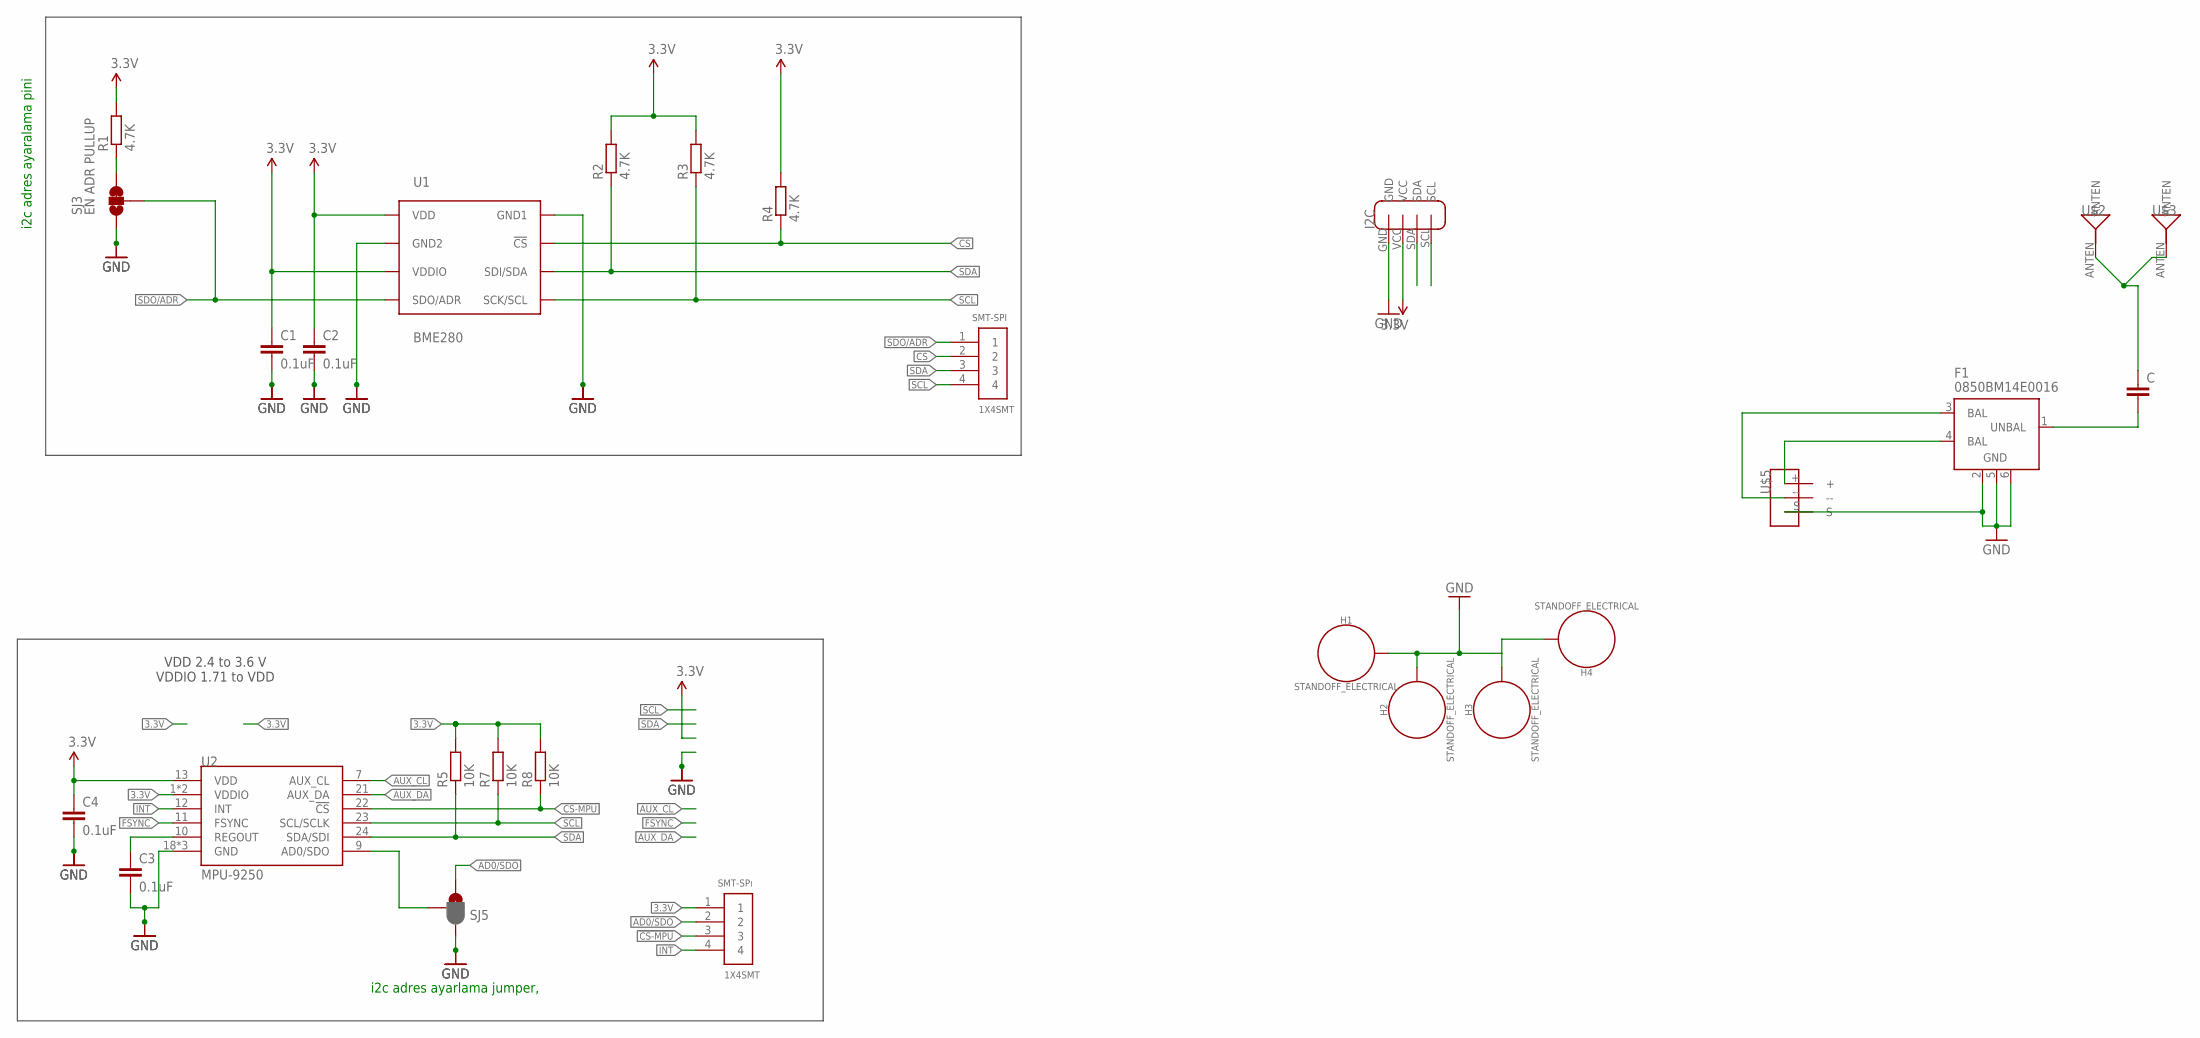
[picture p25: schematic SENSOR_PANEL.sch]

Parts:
C: C-EUC0805; C0805
C1, C2, C3, C4: 0.1uF; C0805
F1: 0850BM14E0016; 2450BM15A0002
H1, H2, H3, H4: STANDOFF_ELECTRICAL; STANDOFF-ELECTRICAL
R1, R2, R3, R4: 4.7K; R0805
R5, R7, R8: 10K; R0805
SJ3: EN ADR PULLUP; PAD-JUMPER-3-2OF3_NC_BY_TRACE_YES_SILK_FULL_BOX
SJ5: JUMPER_PAD-3-1&2_NC_BY_PASTE; PAD-HUMPER-3-1&2_NC_BY_PASTE_YES_SILK_FULL_BOX
SMT-SPI: 1X4SMT; 1X4-SMT
SMT-SPı: 1X4SMT; 1X4-SMT
U1: BME280; BME280_LGA
U2: MPU-9250; QFN24_PAD
U$1: I2C
U$2, U$3: ANTEN
U$5: 3PINSENSOR

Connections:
3.3V: C1.1, C2.1, C4.1, R1.2, R2.2, R3.2, R4.2, R5.2, R7.2, R8.2, SMT-SPı.1, U1.P$6 (VDDIO), U1.P$8 (VDD), U2.1 (VDDIO), U2.8 (VDDIO), U2.13 (VDD), U$1.VCC
!CS-MPU: R8.1, SMT-SPı.3, U2.22 (!CS)
AD0/SDO: SJ5.3, SMT-SPı.2
ADSD_STUB: SJ5.2, U2.9 (AD0/SDO)
AUX_CL: U2.7 (AUX_CL)
AUX_DA: U2.21 (AUX_DA)
CS: R4.1, SMT-SPI.2, U1.P$2 (!CS)
FSYNC: U2.11 (FSYNC)
GND: C1.2, C2.2, C3.2, C4.2, F1.2 (GND), F1.5 (GND), F1.6 (GND), H1.P1, H2.P1, H3.P1, H4.P1, SJ3.1, SJ5.1, U1.P$1 (GND1), U1.P$7 (GND2), U2.18 (GND), U2.20 (GND), U2.CENTER (GND), U$1.GND, U$5.S
INT: SMT-SPı.4, U2.12 (INT)
unnamed: C.2, F1.1 (UNBAL)
unnamed: R1.1, SJ3.3
unnamed: C.1, U$2.ANTEN, U$3.ANTEN
unnamed: F1.3 (BAL), U$5.--
unnamed: F1.4 (BAL), U$5.+
REGOUT: C3.1, U2.10 (REGOUT)
SCL: R3.1, R7.1, SMT-SPI.4, U1.P$4 (SCK/SCL), U2.23 (SCL/SCLK), U$1.SCL
SDA: R2.1, R5.1, SMT-SPI.3, U1.P$3 (SDI/SDA), U2.24 (SDA/SDI), U$1.SDA
SDO/ADR: SJ3.2, SMT-SPI.1, U1.P$5 (SDO/ADR)

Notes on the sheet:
VDD 2.4 to 3.6 V VDDIO 1.71 to VDD
i2c adres ayaralama pini
i2c adres ayarlama jumper,

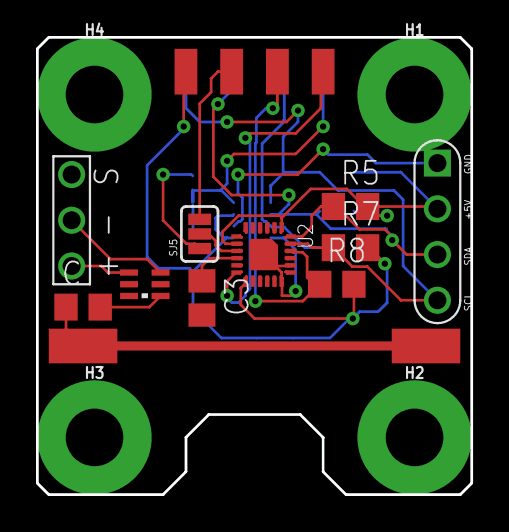
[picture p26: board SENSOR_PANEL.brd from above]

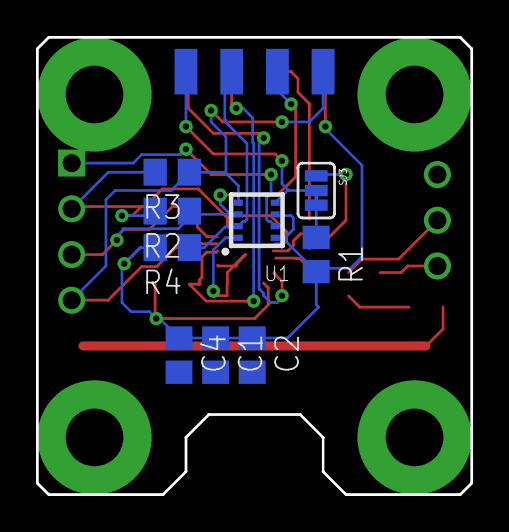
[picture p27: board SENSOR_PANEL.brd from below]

Board: 2 copper layers, 24.1 x 25.4 mm, 27 parts (10 on the bottom side), 16 nets.

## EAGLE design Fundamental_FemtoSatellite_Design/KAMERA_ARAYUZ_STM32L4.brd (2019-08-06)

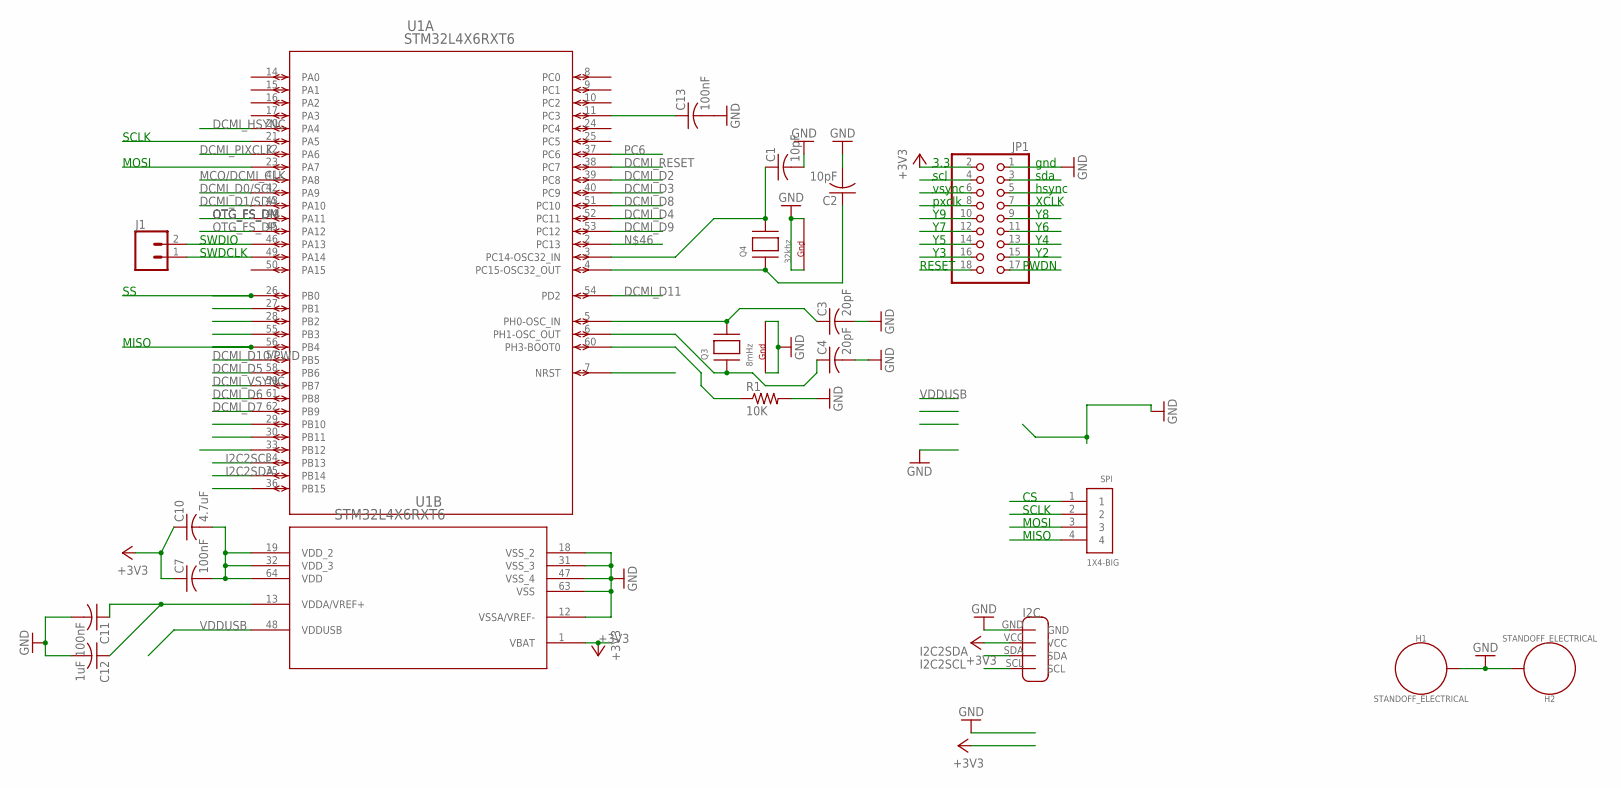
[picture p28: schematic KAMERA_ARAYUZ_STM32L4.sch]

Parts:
C1, C2: 10pF; C0805
C3, C4: 20pF; C0805
C7, C11, C13: 100nF; C0805
C10: 4.7uF; C0805
C12: 1uF; C0805
H1, H2: STANDOFF_ELECTRICAL; STANDOFF-ELECTRICAL
J1: CONN_02; 1X02
JP1: PINHD-2X9-CBIG; 2X09-CLEANBIG
Q3: 8mHz; NX3225
Q4: 32khz; NX3225
R1: 10K; R0805
SPI: 1X4-BIG; 1X04-BIG
U1: STM32L4X6RXT6; LQFP64-10X10MM
U$2: I2C

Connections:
+3V3: C7.1, C10.1, JP1.2, U1.1 (VBAT), U$2.VCC
CS: SPI.1, U1.26 (PB0)
DCMI_D0/SCL: JP1.4, U1.42 (PA9)
DCMI_D1/SDA: JP1.3, U1.43 (PA10)
DCMI_D2: JP1.15, U1.39 (PC8)
DCMI_D3: JP1.16, U1.40 (PC9)
DCMI_D4: JP1.13, U1.52 (PC11)
DCMI_D5: JP1.14, U1.58 (PB6)
DCMI_D6: JP1.11, U1.61 (PB8)
DCMI_D7: JP1.12, U1.62 (PB9)
DCMI_D8: JP1.9, U1.51 (PC10)
DCMI_D9: JP1.10, U1.53 (PC12)
DCMI_D10/PWD: JP1.17, U1.57 (PB5)
DCMI_D11: U1.54 (PD2)
DCMI_HSYNC: JP1.5, U1.20 (PA4)
DCMI_PIXCLK: JP1.8, U1.22 (PA6)
DCMI_RESET: JP1.18, U1.38 (PC7)
DCMI_VSYNC: JP1.6, U1.59 (PB7)
GND: C1.2, C2.2, C3.2, C4.2, C11.2, C12.2, C13.2, H1.P1, H2.P1, JP1.1, Q3.2 (G2), Q3.4 (G1), Q4.2 (G2), Q4.4 (G1), R1.2, U1.12 (VSSA/VREF-), U1.18 (VSS_2), U1.31 (VSS_3), U1.47 (VSS_4), U1.63 (VSS), U$2.GND
I2C2SCL: U1.34 (PB13), U$2.SCL
I2C2SDA: U1.35 (PB14), U$2.SDA
MCO/DCMI_CLK: JP1.7, U1.41 (PA8)
MISO: SPI.4, U1.56 (PB4)
MOSI: SPI.3, U1.23 (PA7)
unnamed: C2.1, Q4.1 (X1), U1.4 (PC15-OSC32_OUT)
unnamed: C3.1, Q3.3 (X2), U1.5 (PH0-OSC_IN)
unnamed: C4.1, Q3.1 (X1), U1.6 (PH1-OSC_OUT)
unnamed: R1.1, U1.60 (PH3-BOOT0)
unnamed: C11.1, C12.1, U1.13 (VDDA/VREF+)
unnamed: C13.1, U1.11 (PC3)
unnamed: C7.2, C10.2, U1.19 (VDD_2), U1.32 (VDD_3), U1.64 (VDD)
unnamed: C1.1, Q4.3 (X2), U1.3 (PC14-OSC32_IN)
OTG_FS_DM: U1.44 (PA11)
OTG_FS_DP: U1.45 (PA12)
PC6: U1.37 (PC6)
SCLK: SPI.2, U1.21 (PA5)
SWDCLK: J1.1, U1.49 (PA14)
SWDIO: J1.2, U1.46 (PA13)
VDDUSB: U1.48 (VDDUSB)

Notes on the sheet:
3.3
scl
vsync
pxclk
RESET
PWDN
XCLK
hsync
sda
gnd
SWDIO
SWDCLK
MISO
MOSI
SCLK

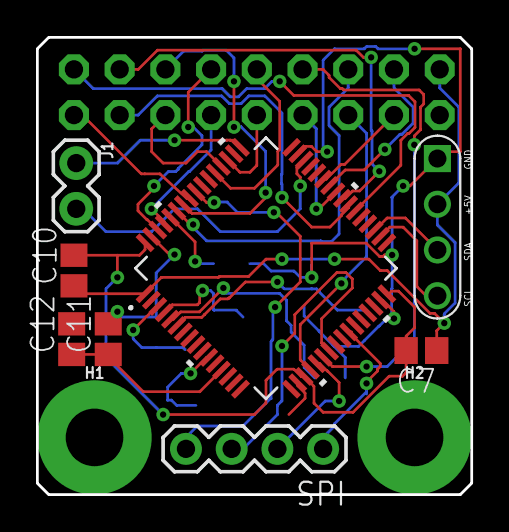
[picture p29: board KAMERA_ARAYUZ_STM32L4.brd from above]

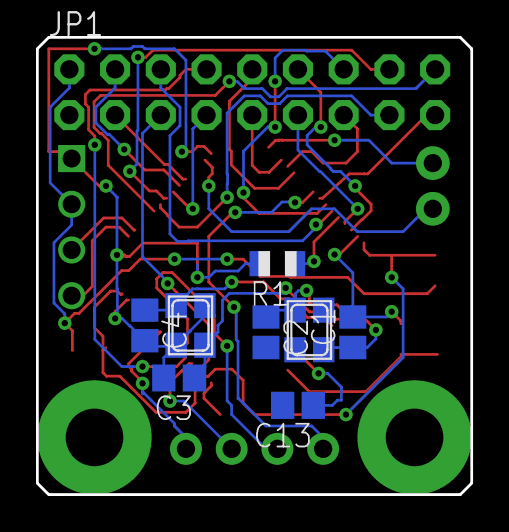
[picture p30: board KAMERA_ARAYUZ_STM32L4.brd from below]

Board: 2 copper layers, 24.1 x 25.4 mm, 19 parts (9 on the bottom side), 34 nets.

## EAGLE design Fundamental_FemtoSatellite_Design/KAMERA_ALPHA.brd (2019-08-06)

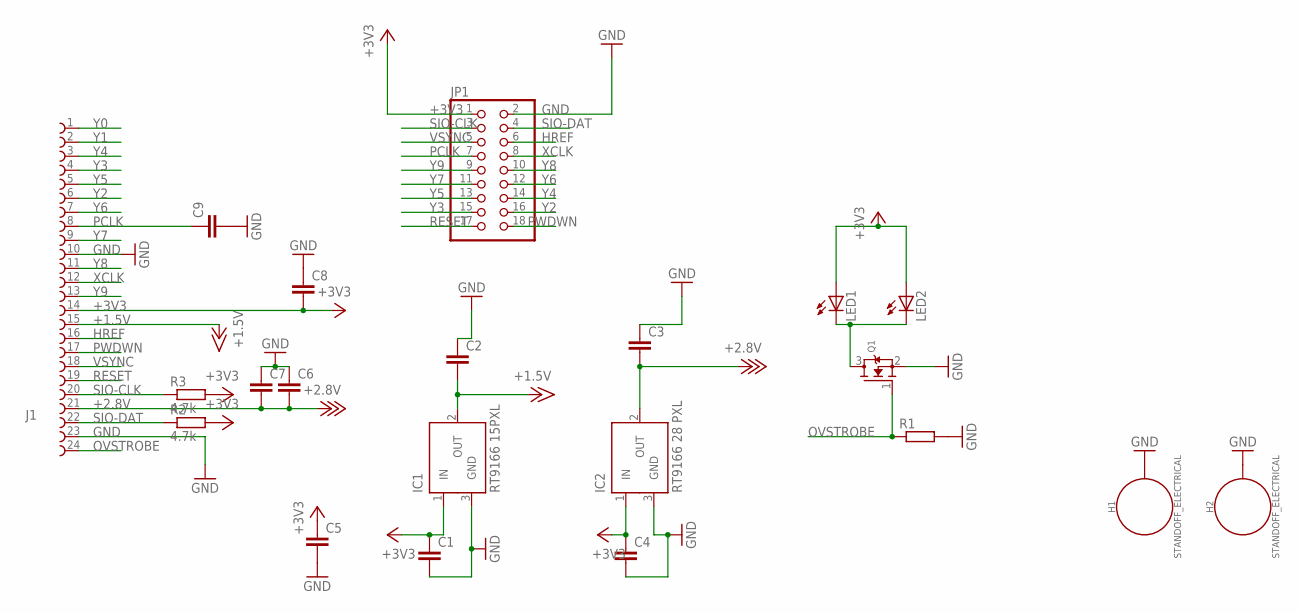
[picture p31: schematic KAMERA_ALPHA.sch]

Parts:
C1, C2, C3, C4, C5, C6, C7, C8, C9: C-EUC0805K; C0805K
H1, H2: STANDOFF_ELECTRICAL; STANDOFF-ELECTRICAL
IC1: RT9166 15PXL; SOT23
IC2: RT9166 28 PXL; SOT23
J1: 68712414022
JP1: PINHD-2X9; 2X09
LED1, LED2: LEDCHIPLED_0805; CHIPLED_0805
Q1: MOSFET-NREFLOW; SOT23
R1: R-EU_R0805; R0805
R2, R3: 4.7k; R0805

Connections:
+1.5V: C2.2, IC1.2 (OUT), J1.15 (10)
+2.8V: C3.2, C6.2, C7.2, IC2.2 (OUT), J1.21 (4)
+3V3: C1.1, C4.1, C5.1, C8.2, IC1.1 (IN), IC2.1 (IN), J1.14 (11), JP1.1, LED1.A, LED2.A, R2.2, R3.2
GND: C1.2, C2.1, C3.1, C4.2, C5.2, C6.1, C7.1, C8.1, C9.2, H1.P1, H2.P1, IC1.3 (GND), IC2.3 (GND), J1.10 (15), J1.23 (2), JP1.2, Q1.2 (S), R1.2
HREF: J1.16 (9), JP1.6
unnamed: LED1.C, LED2.C, Q1.3 (D)
OVSTROBE: J1.24 (1), Q1.1 (G), R1.1
PCLK: C9.1, J1.8 (17), JP1.7
PWDWN: J1.17 (8), JP1.18
RESET: J1.19 (6), JP1.17
SIO-CLK: J1.20 (5), JP1.3, R3.1
SIO-DAT: J1.22 (3), JP1.4, R2.1
VSYNC: J1.18 (7), JP1.5
XCLK: J1.12 (13), JP1.8
Y0: J1.1 (24)
Y1: J1.2 (23)
Y2: J1.6 (19), JP1.16
Y3: J1.4 (21), JP1.15
Y4: J1.3 (22), JP1.14
Y5: J1.5 (20), JP1.13
Y6: J1.7 (18), JP1.12
Y7: J1.9 (16), JP1.11
Y8: J1.11 (14), JP1.10
Y9: J1.13 (12), JP1.9

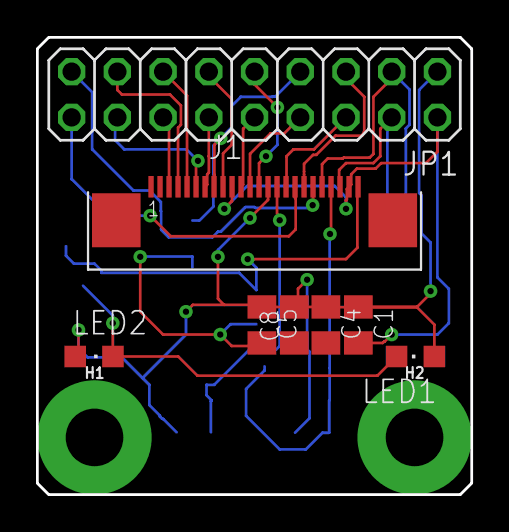
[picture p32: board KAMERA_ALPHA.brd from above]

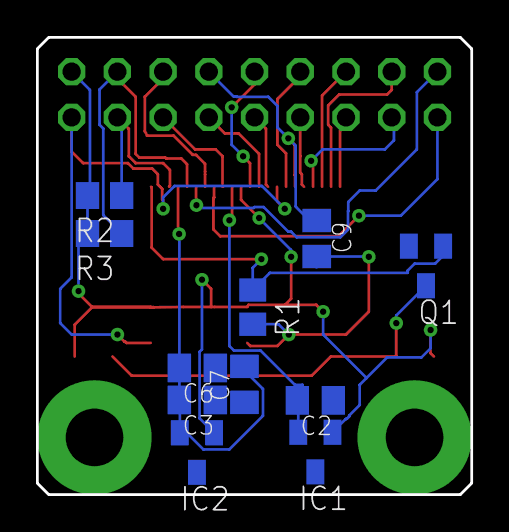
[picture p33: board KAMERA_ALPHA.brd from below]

Board: 2 copper layers, 24.1 x 25.4 mm, 21 parts (11 on the bottom side), 22 nets.

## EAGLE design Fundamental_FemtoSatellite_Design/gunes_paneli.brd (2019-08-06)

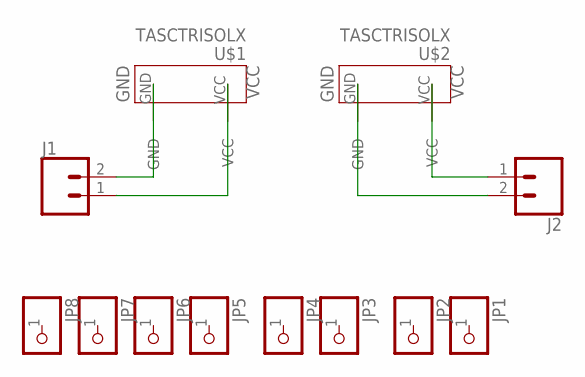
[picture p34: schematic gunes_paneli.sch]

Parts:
J1, J2: CONN_02; 1X02
JP1, JP2, JP3, JP4, JP5, JP6, JP7, JP8: PINHD-1X1CB; 1X01-CLEANBIG
U$1, U$2: TASCTRISOLX; TASCTRİSOLX

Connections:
unnamed: J1.2, U$1.GND
unnamed: J1.1, U$1.VCC
unnamed: J2.1, U$2.VCC
unnamed: J2.2, U$2.GND

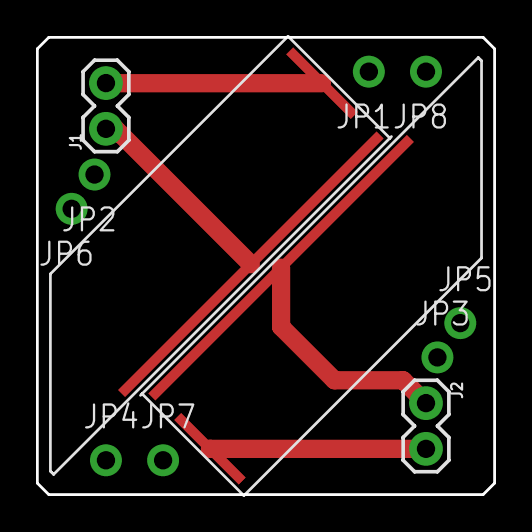
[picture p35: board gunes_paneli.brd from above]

Board: 2 copper layers, 25.4 x 25.4 mm, 12 parts (0 on the bottom side), 4 nets.

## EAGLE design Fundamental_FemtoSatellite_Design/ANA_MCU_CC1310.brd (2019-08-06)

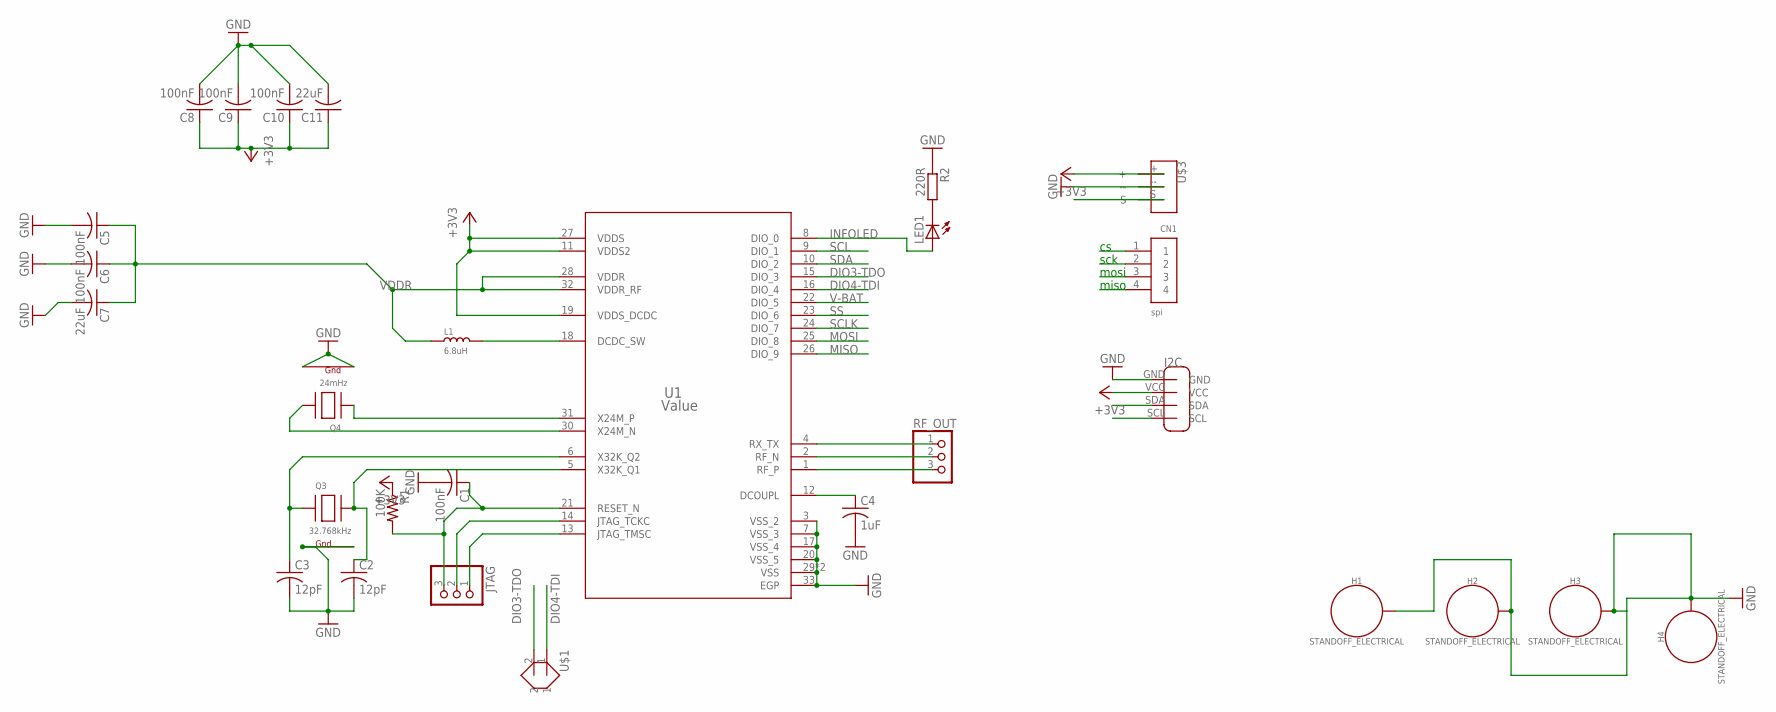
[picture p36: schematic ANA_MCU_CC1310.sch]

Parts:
C1, C5, C6, C8, C9, C10: 100nF; C0805K
C2, C3: 12pF; C0805K
C4: 1uF; C0805K
C7, C11: 22uF; C0805K
CN1: spi; 1X04-CLEANBIG
H1, H2, H3, H4: STANDOFF_ELECTRICAL; STANDOFF-ELECTRICAL
JTAG: PINHD-1X3CB; 1X03-CLEANBIG
L1: 6.8uH; L0805
LED1: LEDCHIP-LED0805; CHIP-LED0805
Q3: 32.768kHz; NX3225
Q4: 24mHz; NX3225
R1: 100K; R0805
R2: 220R; R0805
RF_OUT: PINHD-1X3CB; 1X03-CLEANBIG
U1: Value; RSM0032B
U$1: DCMOTOR
U$2: I2C
U$3: 3PINSENSOR

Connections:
+3V3: C8.1, C9.1, C10.1, C11.1, R1.1, U1.11 (VDDS2), U1.19 (VDDS_DCDC), U1.27 (VDDS), U$2.VCC, U$3.+
DIO3-TDO: U1.15 (DIO_3), U$1.2
DIO4-TDI: U1.16 (DIO_4), U$1.1
GND: C1.2, C2.2, C3.2, C4.2, C5.2, C6.2, C7.2, C8.2, C9.2, C10.2, C11.2, H1.P1, H2.P1, H3.P1, H4.P1, Q3.2 (G2), Q3.4 (G1), Q4.2 (G2), Q4.4 (G1), R2.1, U1.3 (VSS_2), U1.7 (VSS_3), U1.17 (VSS_4), U1.20 (VSS_5), U1.29 (VSS), U1.33 (EGP), U1.V (VSS), U$2.GND, U$3.--
INFOLED: LED1.A, U1.8 (DIO_0)
MISO: CN1.4, U1.26 (DIO_9)
MOSI: CN1.3, U1.25 (DIO_8)
unnamed: Q4.3 (X2), U1.30 (X24M_N)
unnamed: C3.1, Q3.1 (X1), U1.6 (X32K_Q2)
unnamed: Q4.1 (X1), U1.31 (X24M_P)
unnamed: LED1.C, R2.2
unnamed: L1.2, U1.18 (DCDC_SW)
unnamed: C2.1, Q3.3 (X2), U1.5 (X32K_Q1)
unnamed: C1.1, JTAG.3, R1.2, U1.21 (RESET_N)
unnamed: JTAG.2, U1.14 (JTAG_TCKC)
unnamed: JTAG.1, U1.13 (JTAG_TMSC)
unnamed: C4.1, U1.12 (DCOUPL)
unnamed: RF_OUT.3, U1.1 (RF_P)
unnamed: RF_OUT.2, U1.2 (RF_N)
unnamed: RF_OUT.1, U1.4 (RX_TX)
SCL: U1.9 (DIO_1), U$2.SCL
SCLK: CN1.2, U1.24 (DIO_7)
SDA: U1.10 (DIO_2), U$2.SDA
SS: CN1.1, U1.23 (DIO_6)
V-BAT: U1.22 (DIO_5), U$3.S
VDDR: C5.1, C6.1, C7.1, L1.1, U1.28 (VDDR), U1.32 (VDDR_RF)

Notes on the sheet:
sck
mosi
miso



Board: 2 copper layers, 24.1 x 25.4 mm, 28 parts (7 on the bottom side), 26 nets.

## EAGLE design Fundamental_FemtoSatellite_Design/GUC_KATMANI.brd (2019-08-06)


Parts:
C1, C2, C3: 4.7uF; C0805K
C4: 0.01uF; C0805K
H1, H2, H3, H4: STANDOFF_ELECTRICAL; STANDOFF-ELECTRICAL
JP1: PINHD-1X1CB; 1X01-CLEANBIG
L1: 22uH; L0805
PANEL1, PANEL4: 1X4-CLEANBIG; 1X04-CLEANBIG
R1, R3, R8: 4.42M; R0805
R2: 15.62M; R0805
R4: 4.02; R0805
R5: 5.90M; R0805
R6: 5.60M; R0805
R7: 4.22M; R0805
R9: 1.43M; R0805
RFOUT: PINHD-1X3CB; 1X03-CLEANBIG
U1: BQ25504_RGT_16; RGT16_1P7X1P7
U$1: 2PINKLEMENS
U$2: CR1220SMT; CR1220-SMD
U$3: I2C

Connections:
EPAD: U1.17 (EPAD)
GND: C1.1, C2.1, C3.1, C4.2, H1.P1, H2.P1, H3.P1, H4.P1, PANEL1.1, PANEL1.2, PANEL4.1, PANEL4.2, R2.1, R5.1, R6.1, R8.2, U1.1 (VSS_2), U1.5 (OT_PROG), U1.12 (AVSS), U1.13 (VSS), U$1.GND, U$2.+$1 (+), U$2.+$2 (+1)
unnamed: R2.2, R3.1, U1.3 (VOC_SAMP)
unnamed: C4.1, U1.4 (VREF_SAMP)
unnamed: R4.1, R5.2, U1.6 (VBAT_OV)
unnamed: R1.2, R4.2, U1.7 (VRDIV)
unnamed: R1.1, R6.2, R9.1, U1.8 (VBAT_UV)
unnamed: R7.2, R8.1, U1.10 (OK_PROG)
unnamed: L1.1, U1.16 (LBST)
unnamed: R7.1, R9.2, U1.9 (OK_HYST)
unnamed: C1.2, C2.2, U1.15 (VSTOR)
V+: U1.14 (VBAT), U$1.VIN, U$2.-
VBAT-OK: JP1.1, U1.11 (VBAT_OK)
VCC: C3.2, L1.2, PANEL1.3, PANEL1.4, PANEL4.3, PANEL4.4, R3.2, U1.2 (VIN_DC)


Board: 2 copper layers, 24.1 x 25.4 mm, 26 parts (1 on the bottom side), 13 nets.

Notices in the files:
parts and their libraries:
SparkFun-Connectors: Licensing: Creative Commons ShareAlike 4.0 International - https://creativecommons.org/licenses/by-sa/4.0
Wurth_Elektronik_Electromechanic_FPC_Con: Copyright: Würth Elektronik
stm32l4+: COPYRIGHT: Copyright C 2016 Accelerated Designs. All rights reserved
